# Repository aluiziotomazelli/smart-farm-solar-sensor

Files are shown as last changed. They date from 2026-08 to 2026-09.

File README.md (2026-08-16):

# Smart Farm Solar Sensor Node






A modular, low-power IoT peripheral node based on the **Seeed Studio XIAO ESP32-C3**, designed to measure real-time solar irradiance ($W/m^2$), estimate photovoltaic generation capacity for a 2.64 kWp solar array, monitor ambient/panel temperature and battery health, and broadcast telemetry via **ESP-NOW** to the central Smart Farm Hub.

---

## 1. Physical Principle & Measurement Model

- **Sensor Element:** Dedicated **5W** polycrystalline photovoltaic panel installed at the same tilt, azimuth, and environmental conditions as the main array.
- **Quantity Measured:** Short-circuit current ($I_{sc}$). $I_{sc}$ is strictly proportional to solar irradiance ($W/m^2$) and virtually immune to temperature drift ($\approx +0.04\% / ^\circ\text{C}$).
- **Precision Current Sensing:** High-side **INA226** power monitor with a **$0.1\Omega$ (SMD R100)** shunt resistor.
- **Thermal Monitoring & MPPT Compensation:** **DS18B20** 1-Wire temperature sensor attached to the panel to account for the negative temperature coefficient of photovoltaic cells ($\gamma_{Pmax} \approx -0.35\% / ^\circ\text{C}$).
- **Battery Health:** 1S Li-Po / 18650 voltage divider connected to ADC with calibration and threshold classification.

### Scale Matching & Empirical Benchmarks
- Nominal Panel $I_{sc}$ (at STC 1000 W/m²): $600\text{ mA}$
- Midday Empirical Peak: $720\text{ mA}$ ($1200\text{ W/m}^2$)
- Shunt Voltage at Peak: $V_{shunt} = 720\text{ mA} \times 0.1\Omega = 72\text{ mV}$ (88% of INA226 $\pm 81.92\text{ mV}$ full-scale range).

$$\text{Irradiance } (W/m^2) = \frac{I_{sc\_ma} \times 1000}{600} = \frac{I_{sc\_ma} \times 5}{3}$$

$$\text{Estimated STC Array Capacity } (W) = \frac{I_{sc\_ma} \times 2640\text{ W}}{600\text{ mA}} = I_{sc\_ma} \times 4.4$$

---

## 2. Hardware Pinout & Schematic (Seeed XIAO ESP32-C3)

### Pinout Table

| Pin | GPIO | Constant | Description |
| :----- | :--- | :--- | :--- |
| **D0** | `GPIO 2`  | `BATTERY_LEVEL_GPIO` | ADC battery divider input (240k / 240k, ADC1_CH2) |
| **D1** | `GPIO 3`  | `INA_ALERT_GPIO` | Conversion-ready alert & deep sleep dawn wake trigger  |
| **D2** | `GPIO 4`  | `STATUS_LED_GPIO` | Status LED visual indicator (diagnostic / state) |
| **D3** | `GPIO 5`  | `INA_VCC_GPIO` | Power gate control for INA226 power line |
| **D4** | `GPIO 6`  | `I2C_SDA_GPIO` | I2C Data line for INA226 |
| **D5** | `GPIO 7`  | `I2C_SCL_GPIO` | I2C Clock line for INA226 |
| **D6** | `GPIO 21` | *(Free)* | UART0 TX (Debug serial console) |
| **D7** | `GPIO 20` | *(Free)* | UART0 RX (Debug serial console) |
| **D8** | `GPIO 8`  | `DS18B20_GPIO` | 1-Wire data bus for DS18B20 digital temperature sensor |
| **D9** | `GPIO 9`  | `BOOT_BUTTON_GPIO` | Boot button / manual OTA mode trigger |
| **D10**| `GPIO 10` | *(Free)* | General purpose I/O |

### Circuit Schematic

Solar Sensor Schematic

---

## 3. Architecture & Task Concurrency

```
                        +---------------------------+
                        |     TelemetrySnapshot     | (Atomic thread-safe cache)
                        +---------------------------+
                               ^              ^
                updates battery|              |updates current & yield
                & temperature  |              |
                    +----------+--+        +--+---------------+
                    |SlowSensorsTask|       | InaSensorTask    |
                    | (Every 60s) |        | (Conversion sync)|
                    +------+------+        +--+---------------+
                           |                  |
                           v                  v
                 [DS18B20 + Battery]     [INA226 I2C]
                                              |
                                              v (ESP-NOW broadcast)
                                     +-----------------+
                                     | Smart Farm Hub  |
                                     +-----------------+
```

- **`InaSensorTask`**: High-frequency sampling task synchronized with INA226 conversion-ready interrupts. Updates exponential moving average (EMA) current and broadcasts `SolarSensorReport` via ESP-NOW.
- **`SlowSensorsTask`**: Low-frequency background task executing non-blocking battery ADC sampling (~16ms) and DS18B20 temperature conversions (~800ms) once per minute without stalling real-time control loops.
- **`DayNightController`**: Astronomical calculation engine determining solar noon, sunrise, sunset, and solar declination to dynamically orchestrate night deep-sleep modes.
- **`SolarSensorNvs`**: Dual-tier storage manager keeping runtime state in RTC Fast RAM across deep sleep cycles and committing to NVS Flash on dusk transitions.
- **`CommandHandler`**: Receives and executes remote commands via ESP-NOW (`SYNC_TIME`, `START_OTA`, `REBOOT`).

---

## 4. Telemetry Format (`SolarSensorReport`)

ESP-NOW payload is packed to **27 bytes** (`#pragma pack(push, 1)`):

```cpp
struct SolarSensorReport
{
    PowerProfile power_profile;   ///< Node energy mode (ALWAYS_ON, LOW_POWER, DEEP_SLEEP)
    uint16_t isc_current_ma;      ///< Instantaneous short-circuit current in mA (0 - 819 mA)
    uint16_t irradiance_wm2;      ///< Estimated solar irradiance in W/m² (0 - 1200 W/m²)
    int16_t  panel_temp_c;        ///< Sensor panel temperature in 0.1 °C (e.g. 255 = 25.5 °C)
    uint16_t battery_mv;          ///< Sensor node battery voltage in mV
    uint8_t  battery_percent;     ///< Sensor node battery percentage level (0-100%)
    BatteryState battery_state;   ///< Sensor node battery state (UNKNOWN, CRITICAL, LOW, NORMAL, FULL)
    SensorStatus status;          ///< Sensor health status (OK, ERROR_HARDWARE, etc.)
    uint16_t max_current_ma;      ///< Daily peak current recorded
    uint32_t daily_yield_mah;     ///< Accumulated daily current integral in mAh
    bool     is_night_mode;       ///< Night mode status flag
    uint64_t unix_time;           ///< UTC Epoch timestamp in milliseconds (0 if unsynced)
};
```

---

## 5. Building and Flashing Firmware

### Prerequisites
- ESP-IDF **v5.1+** (v5.5 recommended)

```bash
# Export ESP-IDF environment
source $HOME/paht_to_your_esp-idf/export.sh

# Build target firmware
idf.py set-target esp32c3
idf.py build

# Flash to connected device
idf.py -p /dev/ttyACM0 flash monitor
```

---

## 6. Running Host-Based Tests (Linux)

All components are fully decoupled through abstract interfaces and testable on Linux host using GoogleTest and GoogleMock without physical hardware.

### Running Individual Test Suites
```bash
cd host_test/test_slow_sensors_task
idf.py build
./build/test_slow_sensors_task.elf
```

### Running All Test Suites with CTest
```bash
cd host_test
mkdir -p build && cd build
cmake ..
ctest --output-on-failure
```

### Generating Unified Code Coverage
```bash
cd host_test/build
cmake --build . --target run_all_tests
# HTML report generated in host_test/coverage/index.html
```

---

## 7. License

This project is licensed under the MIT License - see the [LICENSE](LICENSE) file for details.

### Third-Party Acknowledgments

This project incorporates or links to the following third-party open-source libraries and drivers:

- **[espressif/onewire_bus](https://github.com/espressif/idf-extra-components/tree/master/onewire_bus)**: Copyright (c) Espressif Systems (Shanghai) CO LTD — Licensed under the [Apache License 2.0](https://www.apache.org/licenses/LICENSE-2.0).
- **[ESP-IDF](https://github.com/espressif/esp-idf)**: Copyright (c) Espressif Systems (Shanghai) CO LTD — Licensed under the [Apache License 2.0](https://www.apache.org/licenses/LICENSE-2.0).
- **[Embedded Template Library (ETL)](https://www.etlcpp.com/)**: Copyright (c) John Wellbelove — Licensed under the [MIT License](https://opensource.org/licenses/MIT).

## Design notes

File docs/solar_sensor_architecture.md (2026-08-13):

# Architecture and Testability Plan (Host-Test / TDD) - SolarSensor

## 1. Overview and Physical Model

The **SolarSensor** is a peripheral sensor node based on the **Seeed XIAO ESP32-C3** microcontroller, designed to monitor solar irradiance in real time and estimate the instantaneous power generation capacity of a **2.64 kWp (8 x 330W)** photovoltaic array operating with an inverter and no battery bank.

### 1.1 Measurement Principle
- **Sensor Element:** **5W** photovoltaic panel (polycrystalline), installed in the same location, tilt, orientation, temperature, and soiling conditions as the main array.
- **Measured Quantity:** Short-circuit current ($I_{sc}$). The $I_{sc}$ current is directly proportional to solar irradiance ($W/m^2$). Open-circuit voltage ($V_{oc}$) measurement was discarded because it varies little with irradiance.
- **Measurement Hardware:** **INA226** IC connected via **I2C** with a **$0.1\Omega$ (SMD R100)** shunt resistor.
- **Scale Matching:**
  - 5W Panel Specifications: $P_{max} = 5\text{W}$, $V_{oc} = 11.2\text{V}$, $V_{mp} = 9.25\text{V}$, $I_{sc\_nominal} = 0.6\text{A}$ (measured up to $0.7\text{A}$ under full sun).
  - Shunt voltage at $0.7\text{A}$: $V_{shunt} = 0.7\text{A} \times 0.1\Omega = 70\text{mV}$.
  - INA226 limit: $\pm 81.92\text{mV}$ (full scale of $819.2\text{mA}$ with $25\mu\text{A}/LSB$ resolution).
  - The measured peak of $0.7\text{A}$ operates at **~85% of full scale**, providing excellent resolution and 15% safety margin against overcurrent.

### 1.2 Physical Irradiance Model and Empirical Benchmarks

- **Datasheet Specifications (STC: 1000 W/m² @ 25°C)**:
  - Nominal Short-Circuit Current: $I_{sc\_nominal} = 600\text{ mA}$ ($0.6\text{ A}$).
  - Nominal Solar Irradiance: $1000\text{ W/m}^2$.

- **Empirical Field Measurement Benchmark**:
  - Measured at midday (clear sky, panel perpendicular to sun): $I_{sc\_measured} = 720\text{ mA}$.
  - Equivalent Solar Irradiance:
    $$\text{Irradiance} = \frac{720\text{ mA}}{600\text{ mA}} \times 1000\text{ W/m}^2 = 1200\text{ W/m}^2$$
  - INA226 Full Scale Verification ($R_{shunt} = 0.1\Omega$):
    $$V_{shunt} = 720\text{ mA} \times 0.1\Omega = 72\text{ mV}$$
    Operates at **88% of INA226 full-scale** ($\pm 81.92\text{ mV}$ / $819.2\text{ mA}$ max), providing a 100 mA (12%) safety margin.

- **Irradiance and STC Power Conversion Formulas**:
  1. **Irradiance Calculation ($W/m^2$)**:
     $$\text{irradiance\_wm2} = \frac{I_{sc\_ma} \times 1000}{600} = \frac{I_{sc\_ma} \times 5}{3}$$
  2. **Nominal Main Array STC Capacity ($W$)**:
     $$\text{estimated\_power\_w} = \frac{I_{sc\_ma} \times 2640\text{ W}}{600\text{ mA}} = I_{sc\_ma} \times 4.4$$

### 1.3 Temperature Effects and High-Precision MPPT Thermal Compensation

- **Why Short-Circuit Current ($I_{sc}$) Measures Pure Irradiance**:
  - The temperature coefficient of short-circuit current ($\alpha_{Isc}$) is negligible ($\approx +0.04\% / ^\circ\text{C}$).
  - Variations in cell temperature (10°C to 60°C) affect $I_{sc}$ by less than 1.5%. Therefore, $I_{sc}$ provides a temperature-immune measurement of pure solar irradiance ($W/m^2$).

- **Why a Panel Temperature Sensor Is Required for Maximum MPPT Precision**:
  - Photovoltaic cell open-circuit voltage ($V_{oc}$) and maximum power ($P_{max}$) have a strong **negative temperature coefficient** ($\gamma_{Pmax} \approx -0.35\% / ^\circ\text{C}$).
  - **Hot Conditions (55°C cell temp)**: The main array's MPPT output drops by $\sim 10.5\%$ ($2362\text{ W}$ instead of $2640\text{ W}$ nominal at 1000 W/m²).
  - **Cold Conditions (15°C cell temp)**: The main array's MPPT output increases by $\sim +3.5\%$ ($2732\text{ W}$ at 1000 W/m²).
  - **Future Hardware Addendum**: Adding a panel temperature sensor (e.g., DS18B20 / NTC attached to the back of the sensor panel) will allow applying the thermal correction factor:
    $$\text{Thermal\_Factor} = 1.0 + (T_{panel} - 25^\circ\text{C}) \times (-0.0035)$$
    $$P_{mppt\_compensated} = \text{estimated\_power\_w} \times \text{Thermal\_Factor}$$

---

## 2. Data Structures and Protocol

### 2.1 Local Persistence (`SolarStats` in `solar_sensor_stats.hpp`)
Maintained in **RTC RAM** (survives *deep sleep*) and synchronized periodically with **NVS**.

| Field | Type | Description |
| :--- | :--- | :--- |
| `magic` | `uint16_t` | Validation identifier (`0x534F` = "SO") |
| `version` | `uint8_t` | Persistence structure version |
| `gpio_wakeup_enabled`  | `bool` | External wakeup interrupt enable status |
| `is_night_mode` | `bool` | Flag indicating whether the node is operating in night mode |
| `last_battery_mv` | `uint16_t` | Last measured node battery voltage in mV |
| `last_battery_percent` | `uint8_t` | Last node battery percentage (0-100%) |
| `last_battery_state` | `BatteryState` | Battery classification (NORMAL, LOW, CRITICAL) |
| `max_current_ma` | `uint16_t` | Highest short-circuit current recorded during the day |
| `min_day_current_ma` | `uint16_t` | Lowest current recorded during the daytime period |
| `daily_yield_mah` | `uint32_t` | Accumulated daily current integral in mAh |
| `shunt_zero_offset_uv` | `int16_t` | INA226 zero offset measured during the night |
| `crc` | `uint32_t` | CRC32 for memory integrity validation |

### 2.2 ESP-NOW Telemetry (`SolarSensorReport` in `farm_protocol_types.hpp`)
Packed binary payload (`#pragma pack(push, 1)`), totaling **27 bytes** (ESP-NOW maximum: 230 bytes).

```cpp
struct SolarSensorReport
{
    PowerProfile power_profile;   ///< Node energy mode (ALWAYS_ON, LOW_POWER, DEEP_SLEEP)
    uint16_t isc_current_ma;      ///< Instantaneous short-circuit current in mA (0 - 819 mA)
    uint16_t irradiance_wm2;      ///< Estimated solar irradiance in W/m² (0 - 1200 W/m²)
    int16_t  panel_temp_c;        ///< Sensor panel temperature in 0.1 °C resolution (e.g. 255 = 25.5 °C, INT16_MIN if no sensor)
    uint16_t battery_mv;          ///< Sensor node battery voltage in mV
    uint8_t  battery_percent;     ///< Sensor node battery percentage level (0-100%)
    BatteryState battery_state;   ///< Sensor node battery classification
    SensorStatus status;          ///< Sensor health status (OK, ERROR_HARDWARE, etc.)
    uint16_t max_current_ma;      ///< Current peak recorded during the current day
    uint32_t daily_yield_mah;     ///< Accumulated daily current integral in mAh
    bool     is_night_mode;       ///< Indicates whether the node is in night mode
    uint64_t unix_time;           ///< UTC Epoch timestamp in ms (0 if not synchronized)
};
```

---

## 3. Software Architecture and Tasks
```
               +-------------------------------------------------------+
               |                   Hardware / INA226                   |
               +-------------------------------------------------------+
                                           | I2C Master (400kHz via IIna226Driver)
                                           v
               +-------------------------------------------------------+
               |                  ina_sensor_task                      |
               |  * Runs at 4-8 Hz                                     |
               |  * Reads INA226 registers via IIna226Driver           |
               |  * Exponential Moving Average (EMA) Digital Filter     |
               |  * Delta Detection (Delta I > 3% or 10mA)             |
               |  * Direct non-blocking ESP-NOW Telemetry Dispatch      |
               +-------------------------------------------------------+
                                 |                     |
             (Direct ESP-NOW TX) |                     | (Queue: InaSample)
                                 v                     v
+----------------------------------+   +----------------------------------+
|          EspNowManager           |   |            Main Task             |
| * Internal Queue & Worker Task   |   | * System State Machine & Storage |
| * Fire-and-Forget Radio TX       |   | * InaSample Consumer & Stats     |
| * Delta-triggered + 1s Heartbeat |   | * Read Error Counter & Watchdog  |
+----------------------------------+   | * Auto-Reboot on Hardware Error  |
                                       +----------------------------------+
```

1. **`InaSample` Data Contract (`ina_sensor_types.hpp`):**
   ```cpp
   struct InaSample {
       uint16_t  isc_current_ma;    ///< Instantaneous short-circuit current in mA
       uint16_t  bus_voltage_mv;    ///< Measured shunt/bus voltage
       bool      delta_detected;    ///< Flag indicating change exceeding delta threshold
       esp_err_t status;            ///< ESP_OK or I2C/INA226 hardware error status
       int64_t   timestamp_us;      ///< Microsecond timestamp of reading
   };
   ```

2. **`ina_sensor_task` (Frequency: 4 to 8 Hz):**
   - Performs periodic INA226 readings through `IIna226Driver`.
   - Applies Exponential Moving Average (EMA) digital filtering.
   - Detects abrupt irradiance changes ($\Delta I_{sc} > 3\%$ or $> 10\text{mA}$).
   - **Telemetry Dispatch:** On delta detection or 1s heartbeat, directly calls non-blocking `espnow_.send_data()` if reporting is enabled.
   - **Main Task Notification:** Enqueues `InaSample` (containing reading or `status` error) to `ina_sample_queue_`.

3. **`Main Task` (System Coordinator & Health Monitor):**
   - Consumes `InaSample` from `ina_sample_queue_`.
   - **Error Handling & Auto-Reboot:** 
     - Tracks consecutive I2C/hardware errors (`status != ESP_OK`).
     - **Watchdog Timeout:** Waits on `xQueueReceive` with a 2-second timeout. If `ina_sensor_task` freezes or fails 5 consecutive times, sets `stats_.status = SensorStatus::ERROR_HARDWARE` and triggers a clean system restart (`hal_system_.restart()`).
   - Manages state machine (`INIT`, `DAY_ACTIVE`, `DUSK_CHECK`, `NIGHT_SLEEP`, `OTA_MODE`).
   - Toggles `ina_sensor_task.set_reporting_enabled(false)` during `OTA_MODE` or `NIGHT_SLEEP`.

4. **INA226 Power & Hardware Control (High-Side GPIO Power Switching):**
   - **VCC Powering:** INA226 consumes only $\sim 0.33\text{mA}$ during measurement. Powered directly from a high-side ESP32-C3 GPIO pin (`OUTPUT HIGH`).
   - **Hardware Hard Reset:** Driving the VCC GPIO `LOW` for 50ms forces a complete Power-On Reset (POR) on the INA226, clearing stuck I2C bus lines without requiring a full MCU system reboot.
   - **Zero Parasitic Current:** During night `NIGHT_SLEEP`, VCC GPIO is set to `INPUT/LOW` and SDA/SCL lines are disabled, achieving absolute zero ($0.00\mu\text{A}$) parasitic draw.

5. **INA226 Dual-Mode ALERT Pin Strategy:**
   A single physical GPIO pin connected to the INA226 `ALERT` output operates in two distinct modes depending on system state:

   | Phase / State | INA226 ALERT Mode | ESP32-C3 Pin Configuration | Behavior / Function |
   | :--- | :--- | :--- | :--- |
   | **Day (`DAY_ACTIVE`)** | **Conversion Ready (`CVRF`)** | GPIO Interrupt (`gpio_isr_handler_add`) | INA226 triggers LOW on each completed hardware average. ISR issues `vTaskNotifyGiveFromISR`, waking `ina_sensor_task` with 0% idle CPU usage. |
   | **Night (`NIGHT_SLEEP`)** | **Shunt Over Limit (`SOL`)** | Deep Sleep Wakeup (`esp_deep_sleep_enable_gpio_wakeup`) | INA226 triggers LOW when $V_{shunt} > 0.3\text{mV}$ ($\sim 3\text{mA}$). Wakes the ESP32-C3 precisely at dawn. |

6. **ESP-NOW Radio Strategy:**
   - **Non-blocking** send (*fire-and-forget*) queued in the internal `EspNowManager` task (without waiting for a logical ACK, so the real-time flow is not blocked).
   - **Delta + Heartbeat Report:** Sends a packet when there is a significant current change or every 1 second (heartbeat).

---

## 4. Host Testability Strategy (`host_test`) & TDD

The repository adopts **Test-Driven Development (TDD)** in the native x86 test environment (`host_test`) using **GoogleTest** and **GoogleMock**. No logic or driver functionality should be added without a corresponding unit test.

### 4.1 Dependency Injection (DI) and Hardware Abstraction
All interaction with hardware, file systems, time, and the OS is performed through **pure C++ interfaces**:

- **I2C:** [`idf_hals::II2cHAL`](components/idf_hals/include/interfaces/i_hal_i2c.hpp) (Mock: [`MockI2cHAL`](components/idf_hals/mocks/mock_hal_i2c.hpp))
- **INA226 Driver:** `IIna226Driver` (Mock: `MockIna226Driver`)
- **Timing / RTOS:** [`ITimerHAL`](components/idf_hals/include/interfaces/i_hal_timer.hpp), [`IHalFreertos`](components/idf_hals/include/interfaces/i_hal_freertos.hpp)
- **Power / Sleep:** [`ISleepHAL`](components/idf_hals/include/interfaces/i_hal_sleep.hpp), `IBatteryMonitor`
- **Storage:** [`INvsCore`](main/include/interfaces/i_nvs_core.hpp)

### 4.2 Modules and Test Suites in `host_test`

| Test Suite | Test Target | What is tested / asserted |
| :--- | :--- | :--- |
| `Ina226DriverTest` | `Ina226Driver` | Register writes/reads through `MockI2cHAL`, correct $mV \to mA$ conversion calculation, ALERT register configuration, response to I2C failures (NACK/timeout). |
| `SolarMathTest` | Solar calculation functions | Conversion from $I_{sc} \to \text{Irradiance } (W/m^2)$, 2.64 kWp array power estimation, daily integral in mAh, Exponential Moving Average (EMA) filter. |
| `SolarSensorTaskTest` | Sampling Task | Sampling rate, report triggering by $\Delta I$ variation, instantaneous noise handling, shared state update. |
| `SolarSensorAppTest`  | `SolarSensor` App Class | State machine transitions (Day $\leftrightarrow$ Night), statistics saving to NVS/RTC, OTA trigger dispatch. |

### 4.3 TDD Development Cycle (Red-Green-Refactor)

1. **Step 1 (Red - Write the Test):**
   Create the test file or add a `TEST_F` to the appropriate suite in `host_test/test_solar_sensor/main/`. Define mock expectations (`EXPECT_CALL(...)`) and call the method of the class under test.
2. **Step 2 (Green - Implement the Minimum):**
   Write only the code strictly required in the component/main so the test passes. Run `idf.py host_test` or the host CMake build.
3. **Step 3 (Refactor - Improve Safely):**
   Clean up and optimize the implementation with the assurance that the test suite guarantees no regression has been introduced.

---

## 5. Next Implementation Steps

1. Create the `IIna226Driver` interface and its `MockIna226Driver` mock.
2. Develop the `host_test` tests for `Ina226Driver` based on `MockI2cHAL`.
3. Implement the `Ina226Driver` class until all unit tests pass.
4. Implement the tests for the solar math functions (`SolarMathTest`).
5. Integrate sampling and `SolarSensorReport` generation into `SolarSensor`.

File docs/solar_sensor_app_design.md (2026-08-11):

# Solar Sensor — Design da Aplicação (Revisão de Arquitetura)

> Documento de design resultante da revisão de arquitetura do app `SolarSensor`.
> Complementa [`solar_sensor_architecture.md`](solar_sensor_architecture.md) (visão física/protocolo)
> e [`session-ses_011f.md`](session-ses_011f.md) (visão do `run()` atual).

---

## 1. Requisitos da aplicação

1. **Ler dados do sensor** — `InaSensorTask` (INA226, 4-8 Hz, EMA, delta).
2. **Enviar telemetria via ESP-NOW** quando necessário (delta ou heartbeat 1s). O pacote é primordial para o hub tomar decisões.
3. **Decidir entrada em deep sleep** (dusk/dawn) — com base em corrente + relógio.
4. **Receber comandos do hub** — `start_ota`, `reboot` forçado, `sync_time`.
5. **Processo de OTA completo** — parar o que for supérfluo (inclusive competição de rádio), conectar à internet, processar o OTA, desconectar, reiniciar; no boot seguinte verificar `pending verify`, aguardar o `init()` saudável, aceitar o firmware novo ou dar rollback.
6. **Verificar bateria** e enviar junto com os dados de leitura (não primordial — bateria é só backup). A `InaSensorTask` **não deve** ter acesso aos dados de bateria.

---

## 2. Estado atual (as-is) — fatos verificados no código

| Item | Situação |
|---|---|
| `SolarSensor::run()` | Stub (`solar_sensor.cpp:143-147`): loga e retorna. `main.cpp:162` chama uma vez. |
| `process_ina_samples()`, `enter_deep_sleep()`, `save_persistent_state()`, `recover_ina_hardware()`, `check_firmware()`, `send_ota_report()`, `connect_wifi_with_retry()` | Implementados e testados, **nunca chamados** (o `run()` não os orquestra). |
| Telemetria | A `InaSensorTask` envia, mas o `SolarSensorReport` sai incompleto: bateria/stats/`is_night_mode` = 0; `unix_time` = ms desde o boot (monotônico), **não** epoch. |
| `rx_queue_` (app_rx_queue) | Nunca é consumida — comandos do hub são **descartados**. |
| Triggers de OTA | `btn_trigger_.arm()` e `espnow_trigger_.arm()` **nunca são chamados**; `EspNowOtaTrigger::notify()` não é invocado por ninguém. OTA via trigger está 100% desligado. |
| `send_data(require_ack=false)` | Non-blocking: enfileira na TX queue interna do `EspNowManager` (task própria, prio 9). Bloqueia no máximo 100ms se a fila (30) estiver cheia; retorna `ESP_FAIL` e o produtor reenvia no ciclo seguinte. |
| `CoreStorage` | Já possui `has_valid_time`, `last_sync_unix_time_ms`, `power_profile`, `sleep_interval_s`, `last_wake` (`WakeSource`). |
| `TimeSyncCommand` (farm) | Layout idêntico ao `time_manager::TimeSyncPacket` (12 bytes packed) → cast direto no handler. |
| Protocolo de comandos | Dois níveis: **transporte** `espnow::CommandType` (`protocol_types.hpp`): `START_OTA` (0x01), `REBOOT` (0x02), `SET_REPORT_INTERVAL` (0x03). **Aplicação** `farm::CommandType` (`farm_protocol_types.hpp`): `SLEEP_OVERRIDE` (0x40), `PUMP_*` (0x41/0x42), `SYNC_TIME` (0x43). |
| Bateria | `main.cpp` cria `bat_monitor` mas **não injeta** no `SolarSensor`. |

---

## 3. Decisões de arquitetura (com justificativa)

### D1 — Quem envia a telemetria: a própria `InaSensorTask`

**Decisão:** a task continua sendo a produtora do envio.

**Justificativa:**
- O dado está mais fresco na task (sample acabou de ser lido) e não depende do agendamento do main.
- A preocupação "main ocupado com gravação flash atrasa o pacote" **já é resolvida pelo `EspNowManager`**: ele possui fila TX interna + task própria (prio 9). O produtor apenas enfileira — non-blocking.
- **O `EspNowManager` já é o dispatcher.** Uma classe/task intermediária de dispatch seria uma fila redundante na frente de outra fila (telemetria → queue dispatcher → queue EspNowManager → rádio).
- Só valeria um dispatcher se houvesse necessidade real de **prioridade** (ACK de OTA na frente da telemetria) ou **coalescência** (descartar heartbeat velho). Hoje: YAGNI. Revisitar se virar problema observado.

**Ressalva:** `send_data` pode bloquear até 100ms com a TX queue cheia — aceitável para telemetria; o código já trata falha de envio (não atualiza `last_reported_*` e reenvia no ciclo seguinte).

### D2 — Report completo: `TelemetrySnapshot` compartilhado (mutex)

**Decisão:** um struct de ~25 bytes protegido por mutex, escrito pelo main e lido pela task na hora do envio.

**Justificativa:** a task não pode (e não deve) ter acesso a bateria/stats — esses dados vivem no `SolarSensor`/`BatteryMonitor`. O snapshot transfere só os *valores*, sem acoplar a task a esses componentes. (Tempo é exceção: a task lê o `ITimeManager` diretamente para o `unix_time` — ver D4.)

### D3 — `power_profile`: não entra no snapshot

**Decisão:**
- A task **hardcoda `ALWAYS_ON`** — semanticamente correto, pois ela só envia quando `reporting_enabled_ && sampling_enabled_` (modo dia).
- O report final `DEEP_SLEEP` é **evento do main**: antes de `enter_deep_sleep()`, o main seta `core_.power_profile = DEEP_SLEEP`, monta o `SolarSensorReport` (profile `DEEP_SLEEP`, `is_night_mode=true`, bateria do snapshot) e envia com `require_ack=true` (pode bloquear — é a última coisa antes de dormir).

### D4 — `unix_time` do report: task calcula via `ITimeManager` no envio

**Decisão:** o `unix_time` do report é calculado pela task **no momento do envio**, lendo o relógio de sistema:

```cpp
// InaSensorTask::send_telemetry_report()
report.unix_time = time_.is_synchronized() ? time_.get_timestamp_ms() : 0;
```

A task ganha `time_manager::ITimeManager&` no construtor. O `TelemetrySnapshot` **não carrega nenhum campo de tempo** (nem `unix_time_ms`, nem ponto de sync).

**Justificativa:**
- `ITimeManager::get_timestamp_ms()` lê o relógio de sistema (`gettimeofday`), que no C3 é baseado no RTC e **continua contando durante o deep sleep** — a task obtém o epoch real no instante do envio, sem "ponto de sync" no snapshot nem aritmética monotônica. A premissa do D4 antigo (`esp_timer` sobreviver ao deep sleep) deixa de existir.
- O valor nunca fica defasado: é lido na hora, junto com o sample.
- O snapshot fica mais simples (só bateria/stats/`is_night_mode`).
- Fluxo coerente com o `CommandHandler`: `SYNC_TIME` → `time_manager.sync_from_time_packet()` acerta o relógio de sistema → o próximo report da task já reflete o epoch novo.

**Guard `is_synchronized()`:** sem sync o relógio de sistema está na base (epoch ~0), o que também dispararia o auto-sync do hub por diff enorme. Com o guard, o valor vai `0` = "não sincronizado" (mesma semântica do water-tank com `has_valid_time == false`).

**Responsabilidade do hub (fora deste repo — pode ser feito, o hub ainda não tem `solar_sensor_handler`):** **tolerar `unix_time == 0`** — não disparar auto-sync quando o valor for 0; a detecção de discrepância (diff > 5s) só deve valer para `unix_time > 0`. Sem isso, o `0` causaria tempestade de `sync_time` a cada report.

**Manter o campo no `SolarSensorReport`:** sim — remover seria mudança de protocolo (struct packed, afeta o hub) para economizar 8 bytes num pacote de 27. `0` já significa "não sincronizado".

### D5 — OTA não exige deinit do espnow

**Decisão:** durante o download, `espnow.set_channel_policy(ChannelPolicy::FIXED)` (AP domina o canal); ao falhar, volta `SCAN`. **A amostragem continua** (o watchdog do `process_ina_samples()` permanece vivo) — só o reporting é desligado.

**Justificativa:** a API `set_channel_policy` já existe exatamente para isso; evita o ciclo pesado de `deinit()`/`init()` do EspNowManager.

### D6 — Heartbeat interno do espnow: mantém 0

**Decisão:** a telemetria de 1s **é** o sinal de liveness. O node não precisa (nem deve) saber se está "offline" — isso é responsabilidade de quem monitora (hub). O node mantém `heartbeat_interval_ms = 0`.

**Esclarecimento (estado atual):** `get_offline_peers()` é método **público do `espnow_manager`** (não do hub app) e **ainda não é usado em lugar nenhum**. O hub não tem método próprio de detecção de offline. O `espnow_manager` já faz a detecção internamente, mas a API é pobre: retorna um `etl::vector` com **todos** os nodes offline — o hub precisaria iterar o vetor para saber se um node específico caiu.

**Pendência:** estudo futuro da API do `espnow_manager` (ver §9). Não muda nada no solar sensor por ora.

### D7 — `SLEEP_OVERRIDE`: não se aplica

**Decisão:** comando ignorado (ACK `ERROR_INVALID_DATA`) — é para nodes como o water-tank. O solar sensor não usa `sleep_interval_s` override.

---

## 4. Estrutura proposta (target)

```
                    ┌─────────────────────────────────────────────┐
                    │           SolarSensor (coordenador)         │
                    │  run(): loop ~7Hz (block no sample queue)   │
                    │   ├─ TelemetrySnapshot (escreve)            │
                    │   ├─ CommandHandler.process()               │
                    │   ├─ OtaCoordinator.tick()                  │
                    │   ├─ DayNightController.update()            │
                    │   ├─ battery read (periódico)               │
                    │   └─ save_persistent_state (15min)          │
                    └──────────────┬──────────────────────────────┘
                       samples q   │                │ battery/time/sync
                                  ▼                ▼
                    ┌────────────────────────┐  ┌──────────────────────┐
                    │ InaSensorTask (task)   │  │ BatteryMonitor       │
                    │  - sample + telemetria │  │ TimeManager (sync)   │
                    │  - lê snapshot (mutex) │  └──────────────────────┘
                    └───────────┬────────────┘
                                │ send_data (non-blocking)
                                ▼
                    ┌─────────────────────────────┐
                    │ EspNowManager (JÁ é o       │
                    │ dispatcher: fila + tasks)   │
                    └─────────────────────────────┘
```

**Princípios:**
- **Nenhuma task nova.** O TX já tem task própria no EspNowManager.
- **Nenhuma classe de dispatch nova.** Estado compartilhado para o que é estado; send direto para o que é evento.
- `SolarSensor` vira coordenador fino: o `run()` é um script que faz tick em subsistemas coesos.

---

## 5. Detalhamento por classe

### 5.1 `TelemetrySnapshot` (nova — peça-chave)

```cpp
struct TelemetrySnapshotData {   // ~25 bytes, protegido por mutex
    uint16_t    battery_mv;
    uint8_t     battery_percent;
    farm::BatteryState battery_state;
    uint16_t    max_current_ma;
    uint32_t    daily_yield_mah;
    bool        is_night_mode;
};
```

- **Quem escreve:** main (bateria a cada N segundos, stats após processar samples, `is_night_mode` nas transições).
- **Quem lê:** `InaSensorTask::send_telemetry_report()` (lock → copy → unlock → preenche report; `unix_time` vem do `ITimeManager` — ver D4).
- **Sincronização:** C3 é single-core → mutex simples ou critical section resolve.
- **Injeção:** referência no construtor da task (e no `SolarSensor`). O construtor da task também ganha `time_manager::ITimeManager&` (D4) → atualizar host tests (inclui criar `MockTimeManager`).
- **`power_profile` fica FORA** (ver D3).

### 5.2 `CommandHandler` (nova, pequena, poling do `run()`)

```cpp
CommandHandler(QueueHandle_t rx_queue, IEspNowManager& espnow, ITimeManager& time,
               IOtaTrigger& espnow_ota_trigger, ISystemHAL& hal_system, CoreStorage& core);

void process();   // drena rx_queue_ (chamado no loop ~7Hz)
```

O comando chega no `AppMessage` com `msg_type = COMMAND` e o valor do `CommandType` **no campo `msg.payload_type`** (o transporte encoda o comando nesse campo do header).

| `msg.payload_type` | Ação |
|---|---|
| `espnow::CommandType::START_OTA` (0x01) | `espnow_ota_trigger.notify()` → `OtaCoordinator`. |
| `espnow::CommandType::REBOOT` (0x02) | `hal_system.restart()`. |
| `espnow::CommandType::SET_REPORT_INTERVAL` (0x03) | Fora dos requisitos atuais — ACK `ERROR_INVALID_DATA` (candidato futuro: ajustar o `heartbeat_interval_ms` da task). |
| `farm::CommandType::SYNC_TIME` (0x43) | `time_.sync_from_time_packet(*reinterpret_cast<const TimeSyncPacket*>(msg.payload))`; atualiza `core_.has_valid_time` / `core_.last_sync_unix_time_ms`. |
| `farm::CommandType::SLEEP_OVERRIDE` / `PUMP_*` (0x40-0x42) | Ignora (ACK `ERROR_INVALID_DATA`). |
| qualquer | Se `msg.requires_ack` → `espnow.confirm_reception(msg.sender_id, msg.sequence_number, ok/err)`. |

### 5.3 `OtaCoordinator` (extração — a maior, implementar por último)

Máquina de estados (transpõe reboot):

```
IDLE →(trigger: botão/espnow)→ PREPARING:
         - ina_task.set_reporting_enabled(false)
         - espnow.set_channel_policy(FIXED)
         - wifi connect (retry)
      → DOWNLOADING:
         - ota_manager.start_ota()
         - poll get_status() até DONE/FAILED   [samples continuam → watchdog vivo]
      → SUCCESS → hal_system.restart() → VERIFYING (próximo boot)
      → FAILED  → espnow.set_channel_policy(SCAN); reporting on → IDLE

VERIFYING (boot):
  pending_firmware_verify_ && session_healthy → confirm_app_valid()
      + report OTA_STATUS_REPORT(CONFIRMED_SUCCESS) + commit versão → IDLE
  senão → report OTA_STATUS_REPORT(ROLLBACK_TRIGGERED, HEALTH_CHECK_FAILED)
      + rollback_and_reboot()
```

**Deps:** `ota_manager`, `wifi`, `espnow` (channel policy + `send_data` para o report), `ina_task` (só `set_reporting_enabled`), `hal_system`, `core_`.

**Alternativa de desacoplamento:** interface `IOtaApp` (implementada pelo `SolarSensor`) para os side-effects (`set_telemetry_enabled`, channel policy, reboot). Como os componentes já têm interfaces com mocks no repo, injetar direto é menos abstração nova — decidir na implementação.

### 5.4 `DayNightController` (nova, lógica pura — melhor custo/benefício)

Sem I/O, só decisões → testável sem mock.

- `update(current_ma)`: se dia e `current < threshold` → request sleep.
  - **Com clock válido:** confirma também que a hora está dentro da janela de confiança (**dusk = corrente + relógio**).
  - **Sem clock válido:** usa só corrente — ver D8 abaixo.
- `classify_wake(cause, now)`:
  - `GPIO` (ALERT low) → dia (amanhecer).
  - `TIMER` na hora de calibração → **modo calibração**: ler shunt zero offset (madrugada, sem luz), persistir, voltar a dormir.
  - `TIMER` fora da janela → voltar a dormir.
- **Config:** `dusk_current_threshold_ma` (ver D8), `dusk_hour_window`, `calibration_wake_hour` — `dusk_hour_window` e `calibration_wake_hour` a medir com sensor real (pendente).

### 5.5 `StatsManager` — **adiado**

Stats + NVS permanecem no `SolarSensor`. Extrair apenas quando a integral diária (`daily_yield_mah`) e a calibração de offset ganharem lógica real. O snapshot já desacopla stats da task.

### 5.6 `SolarSensor` (após refactor)

- Construtor perde ~6-7 deps (absorvidas pelos subsistemas).
- `run()` vira orquestração de ticks.
- Mantém: watchdog/recuperação INA, transições de sleep, storage (por ora), composição.

---

## 6. Gaps / pendências de protocolo e código

1. **`START_OTA`/`REBOOT`/`SET_REPORT_INTERVAL` já existem** em `espnow::CommandType` (`protocol_types.hpp`) — não há gap de protocolo para esses. O gap real é de **wiring**: `rx_queue_` não é consumida (comandos nunca despachados) e os triggers não são armados.
2. **Triggers nunca são armados** (`btn_trigger_.arm()`, `espnow_trigger_.arm()`) e `EspNowOtaTrigger::notify()` não é chamado por ninguém → wire do gatilho de OTA é 100% novo.
3. **`unix_time` do report é monotônico**, não epoch — placeholder até a task ler o `ITimeManager` no envio (D4) e o hub tolerar `unix_time == 0`.
4. **`rx_queue_` nunca consumida** → comandos descartados (requisito 4 inteiro em falta).
5. **Bateria não injetada** no `SolarSensor` → campos de bateria sempre 0.
6. **API de offline do `espnow_manager`** — `get_offline_peers()` é público mas não usado; hub não tem detecção própria. Ver §9 (estudo futuro; nada a mudar no node por ora).
7. **Dusk sem clock válido** — comportamento a definir (ver §7).

---

## 7. Decisões em aberto / fechadas

1. **Indireção do `START_OTA`:** manter o `EspNowOtaTrigger` (CommandHandler chama `notify()` → listener) ou o `CommandHandler` chamar o `OtaCoordinator` direto? (Mantive o trigger por reutilizar a abstração `IOtaTrigger` já existente.) — **EM ABERTO**
2. **Dusk sem clock válido** → **FECHADO (D8 abaixo)**.
3. **Granularidade da implementação:** incremental — **FECHADO (§8 abaixo)**.

### D8 — Dusk sem clock válido: corrente abaixo de `DEFAULT_DUSK_CURRENT_MA`

**Decisão:** quando `ITimeManager::is_synchronized() == false`, o `DayNightController`
decide entrar em sleep baseando-se **apenas na corrente**. Threshold inicial:

```cpp
// ina_sensor_types.hpp
/// Corrente abaixo da qual o node considera que é entardecer (dusk).
/// Valor inicial conservador; calibrar com sensor real no campo.
static constexpr uint16_t DEFAULT_DUSK_CURRENT_MA = 1; // < 1 mA → entra em sleep
```

**Justificativa:**
- O node deve ser capaz de entrar em deep sleep mesmo sem nunca ter recebido
  `SYNC_TIME` do hub (ex.: primeiro deploy, hub offline).
- 1 mA é abaixo do ruído de dark current do painel — qualquer irradiância
  real gera corrente muito maior. Conservador o suficiente para não dormir
  durante o dia por falso negativo.
- A constante vive em `ina_sensor_types.hpp`, junto a `DEFAULT_DAWN_WAKEUP_ALERT_LIMIT`
  (mesma convenção: limites de corrente relacionados ao ciclo dia/noite do INA).
- Calibrar o valor real (e a janela de hora) com multímetro/sensor no campo;
  atualizar a constante e o comentário de cálculo no mesmo estilo de
  `DEFAULT_DAWN_WAKEUP_ALERT_LIMIT`.

**Com clock válido:** a janela de hora é AND com a corrente — evita dormir
num pico de nuvem passageira no meio do dia.

---

## 8. Sequência de implementação (incremental, TDD)

> Regra do repo: nenhuma lógica sem teste correspondente (host_test, GoogleTest/GoogleMock).

1. **`TelemetrySnapshot` + `ITimeManager` na task (1a)** — testes: main escreve / task lê; report completo; `unix_time` real via `ITimeManager` (sincronizado) / `0` (não sincronizado). Muda construtor da task — `TelemetrySnapshot&` + `ITimeManager&` → ajustar `SolarSensorTaskTest` e criar `MockTimeManager`.

2. **`BatteryMonitor` injetado no `SolarSensor` (1b)** — adiciona `IBatteryMonitor&` ao construtor de `SolarSensor` e ao wiring em `main.cpp`. Leitura periódica de bateria no `run()` → escreve no snapshot. Testes: snapshot com bateria real; campos não-zero no report.
   > ⚠️ **Atenção:** Os passos 1a e 1b podem ser commitados em qualquer ordem, mas o report só fica completo com os dois aplicados. Enquanto 1b não estiver feito, os campos de bateria do snapshot são inicializados dos valores persistidos no `SolarStats` (carregados no boot via NVS/RTC), o que é aceitável como fallback.

3. **`CommandHandler`** — testes: dispatch `SYNC_TIME`, ignore `SLEEP_OVERRIDE`, ack `confirm_reception`. (Desbloqueia requisito 4.)

4. **`DayNightController`** — testes: dusk só por corrente (`DEFAULT_DUSK_CURRENT_MA`), dusk por corrente+hora (clock válido), `classify_wake` GPIO/TIMER/calibração. (Lógica pura, sem mock.)

5. **`run()` integrando 1-4** — testes de app: drena fila, watchdog restart, dusk → sleep, wake GPIO → dia.
   > **Atenção:** `ota_triggered_` (flag atômica em `SolarSensor`) é setada em `on_ota_triggered()` mas nunca lida. Antes do `OtaCoordinator` existir, o `run()` deve checar essa flag e chamar `espnow_trigger_.notify()` / iniciar o fluxo de OTA inline.

6. **`OtaCoordinator`** — por último (maior; a versão atual dentro do `SolarSensor` já funciona): trigger armado, channel policy, download, verify no boot, rollback.

---

## 9. Estudos futuros (fora do escopo do SolarSensor)

### 9.1 API de detecção de offline no `espnow_manager`

- **Problema:** o `espnow_manager` já detecta offline internamente (e bem), mas a API só expõe `get_offline_peers()` — um `etl::vector` com **todos** os peers offline. O hub precisa iterar o vetor para saber se um node específico está offline.
- **Proposta:** métodos dedicados na API, ex.: `bool is_node_offline(NodeId)` / `is_node_online(NodeId)`, sem expor o vetor.
- **Pergunta em aberto:** a detecção de offline considera **qualquer pacote recebido** (inclusive os internos de comunicação automática — scan, pairing, ack) ou depende do `heartbeat_interval_ms` configurado por peer? Evidência no código: `NOTIFY_LINK_ALIVE` é setado em qualquer recepção válida de pacote (`protocol_types.hpp`). Isso determina se a telemetria de 1s do solar sensor mantém o peer "vivo" no hub.
- **Impacto no solar sensor:** nenhum por ora — o node continua com `heartbeat_interval_ms = 0` (telemetria é o liveness). O estudo é do lado espnow_manager/hub.

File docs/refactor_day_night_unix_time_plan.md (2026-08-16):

# Refactoring Plan: `DayNightController` — Unix Time API + Dawn Alert in mA

## Goal

Two related cleanups to eliminate boilerplate and improve safety:

1. **Replace `(bool is_synced, uint8_t hour, uint8_t minute, uint16_t day_of_year)` params** with `std::optional<time_t> unix_time` across all three `DayNightController` methods. The decomposition of `tm_hour`, `tm_min`, `tm_yday` moves inside the controller, where it belongs (domain logic). The three `localtime_r()` boilerplate blocks scattered in `solar_sensor.cpp` are eliminated.

2. **Replace raw INA226 alert register `DEFAULT_DAWN_WAKEUP_ALERT_LIMIT = 12`** with a human-readable `dawn_alert_current_ma` field in `InaSensorConfig`. The conversion to the raw 16-bit register value is computed once inside `InaSensorTask::prepare_for_sleep()`, using the shunt resistance stored in `Ina226Config`.

---

## User Review Required

> [!IMPORTANT]
> `classify_wake()` currently classifies **any** GPIO wakeup as `DAWN_GPIO`, ignoring time of day. This refactoring is the right moment to also fix that bug (the field sleep/wake loop you observed at dusk). The fix is included in the plan as **Step 2c**. If you want to separate the two concerns into independent commits, let me know.

> [!IMPORTANT]
> `localtime_r()` converts the UTC `time_t` to **local time using the system TZ**. In ESP-IDF, the TZ is configured via `setenv("TZ", ...)`. The controller already has `tz_offset_hours` in `DayNightConfig`, but currently that field is only used conceptually (not in the computation). The tests on the host will call `localtime_r()` with the system TZ, which may differ from the target TZ. This is acceptable since the tests already pass fixed `hour`/`minute` values — but after the refactoring, the host tests need to supply a `time_t` that matches UTC so `localtime_r()` returns the expected values, or we can use `gmtime_r()` + `tz_offset_hours` internally (pure, no system TZ dependency). **Which do you prefer?**
> - Option A: Use `localtime_r()` — simple, relies on system TZ (consistent with how the ESP32 sets TZ via SNTP today).
> - Option B: Use `gmtime_r()` + `config_.tz_offset_hours` — pure, no system-level TZ dependency, easier to test portably.

---

## Open Questions

> [!IMPORTANT]
> **Dawn alert threshold**: Currently `DEFAULT_DAWN_WAKEUP_ALERT_LIMIT = 12` raw units ≈ `0.3 mA`. This is clearly too sensitive (triggered by dusk noise). What should the new `dawn_alert_current_ma` default value be? Suggestion: **`5 mA`** (same as `DEFAULT_DAWN_CURRENT_THRESHOLD_MA`), so that the INA only wakes the MCU when the panel is already producing meaningful current.

---

## Background

### The 3 Boilerplate Blocks in `solar_sensor.cpp`

All three call sites repeat the exact same pattern:

```cpp
// Block 1 — run_day_cycle (L237-248)
bool is_synced = time_manager_.is_synchronized();
uint8_t hour = 0; uint8_t minute = 0; uint16_t day_of_year = 81;
if (is_synced) {
    time_t now = time_manager_.get_timestamp_sec();
    struct tm timeinfo{};
    localtime_r(&now, &timeinfo);
    hour = static_cast<uint8_t>(timeinfo.tm_hour);
    minute = static_cast<uint8_t>(timeinfo.tm_min);
    day_of_year = static_cast<uint16_t>(timeinfo.tm_yday + 1);
}
process_ina_samples(is_synced, hour, minute, day_of_year); // -> should_enter_night_mode

// Block 2 — enter_deep_sleep (L717-728)
// Same 10 lines again -> calculate_night_sleep_time_us

// Block 3 — evaluate_boot_mode (L840-847)
// Partial repeat (only hour) -> classify_wake
```

### Current Signatures (to be replaced)

```cpp
// day_night_controller.hpp
bool should_enter_night_mode(
    uint16_t current_ma,
    bool is_time_synced,
    uint8_t current_hour_local,
    uint8_t current_minute_local,
    uint16_t day_of_year);

WakeType classify_wake(
    bool is_gpio_wakeup,
    uint16_t current_ma,
    bool is_time_synced,
    uint8_t current_hour_local) const;

uint64_t calculate_night_sleep_time_us(
    bool is_time_synced,
    uint8_t current_hour_local,
    uint8_t current_minute_local,
    uint16_t day_of_year) const;
```

---

## Proposed Changes

### Step 1 — INA226 Alert Limit in mA

---

#### [MODIFY] `ina_sensor_types.hpp`

Replace the raw constant with a human-readable default in mA, and update the comment:

```diff
-/**
- * @brief Default Shunt Over Voltage raw threshold for dawn wakeup detection.
- * Calculation: I_dawn = ~0.3 mA, V_sh = 30 uV, raw = 30/2.5 = 12
- */
-static constexpr uint16_t DEFAULT_DAWN_WAKEUP_ALERT_LIMIT = 12;
+/**
+ * @brief Default dawn wakeup current threshold in mA.
+ *
+ * The INA226 SHUNT_OVER_VOLTAGE alert fires when the shunt current
+ * exceeds this value, waking the MCU from deep sleep at dawn.
+ * Must be high enough to reject dusk noise (recommend >= 5 mA).
+ */
+static constexpr uint16_t DEFAULT_DAWN_ALERT_CURRENT_MA = 5;
```

Add a new field to `InaSensorConfig`:

```diff
 struct InaSensorConfig
 {
     uint16_t delta_threshold_ma = 10;
     float delta_threshold_percent = 0.03f;
     uint16_t heartbeat_interval_ms = 1000;
     bool enable_ema_filter = true;
     float ema_alpha = 0.8f;
     uint32_t task_stack_size = 4096;
     UBaseType_t task_priority = 5;
+    uint16_t dawn_alert_current_ma = DEFAULT_DAWN_ALERT_CURRENT_MA; ///< INA dawn wakeup current threshold in mA
     InaNightConfig night_config{};
 };
```

#### [MODIFY] `ina_sensor_task.cpp` — `prepare_for_sleep()`

Replace static constant with dynamic conversion:

```diff
+// INA226 Shunt Voltage LSB = 2.5 uV/LSB.
+// V_shunt_uv = I_ma * R_shunt_mohm  =>  raw = V_shunt_uv / 2.5
+// With R_shunt = 100 mOhm: raw = I_ma * 100 / 2.5 = I_ma * 40
+float r_shunt_mohm = ina_day_config_.r_shunt_ohms * 1000.0f;
+float v_shunt_uv = static_cast<float>(config_.dawn_alert_current_ma) * r_shunt_mohm;
+uint16_t alert_limit = static_cast<uint16_t>(v_shunt_uv / 2.5f);
 err = driver_.configure_alert(
-    static_cast<uint16_t>(ina226::AlertFlag::SHUNT_OVER_VOLTAGE), DEFAULT_DAWN_WAKEUP_ALERT_LIMIT);
+    static_cast<uint16_t>(ina226::AlertFlag::SHUNT_OVER_VOLTAGE), alert_limit);
```

> [!NOTE]
> `InaSensorTask` already receives the `Ina226Config` (which contains `r_shunt_ohms`) through its constructor. The conversion happens once at `prepare_for_sleep()` time — no new dependencies needed.

---

### Step 2 — `DayNightController` Unix Time API

---

#### [MODIFY] `day_night_controller.hpp`

Replace decomposed time params with `std::optional<time_t>`:

```diff
+#include <ctime>
+#include <optional>

 bool should_enter_night_mode(
     uint16_t current_ma,
-    bool is_time_synced,
-    uint8_t current_hour_local,
-    uint8_t current_minute_local,
-    uint16_t day_of_year);
+    std::optional<time_t> unix_time);

 WakeType classify_wake(
     bool is_gpio_wakeup,
     uint16_t current_ma,
-    bool is_time_synced,
-    uint8_t current_hour_local) const;
+    std::optional<time_t> unix_time) const;

 uint64_t calculate_night_sleep_time_us(
-    bool is_time_synced,
-    uint8_t current_hour_local,
-    uint8_t current_minute_local,
-    uint16_t day_of_year) const;
+    std::optional<time_t> unix_time) const;
```

Add a private helper that centralizes the `localtime_r` decomposition:

```cpp
private:
    struct LocalTime {
        uint8_t hour;
        uint8_t minute;
        uint16_t day_of_year;
    };
    LocalTime decompose(time_t unix_time) const;
```

#### [MODIFY] `day_night_controller.cpp`

Add `decompose()` implementation:

```cpp
DayNightController::LocalTime DayNightController::decompose(time_t unix_time) const
{
    struct tm t{};
    localtime_r(&unix_time, &t);
    return {
        static_cast<uint8_t>(t.tm_hour),
        static_cast<uint8_t>(t.tm_min),
        static_cast<uint16_t>(t.tm_yday + 1)
    };
}
```

Update `should_enter_night_mode()`:

```diff
-bool DayNightController::should_enter_night_mode(
-    uint16_t current_ma, bool is_time_synced,
-    uint8_t current_hour_local, uint8_t current_minute_local, uint16_t day_of_year)
+bool DayNightController::should_enter_night_mode(
+    uint16_t current_ma, std::optional<time_t> unix_time)
 {
-    if (is_time_synced) {
+    if (unix_time.has_value()) {
-        SolarDayInfo day_info = calculate_solar_day(day_of_year);
-        float current_time_float = static_cast<float>(current_hour_local) + ...
+        auto [hour, minute, day_of_year] = decompose(*unix_time);
+        SolarDayInfo day_info = calculate_solar_day(day_of_year);
+        float current_time_float = static_cast<float>(hour) + (static_cast<float>(minute) / 60.0f);
         ...
     } else {
         required_samples = config_.unsynced_hysteresis_sample_count;
     }
```

#### 2c — Fix `classify_wake()` — Add Time Window Guard

This is the **bug fix** for the dusk wake loop. With `unix_time` now available:

```cpp
WakeType DayNightController::classify_wake(
    bool is_gpio_wakeup, uint16_t current_ma, std::optional<time_t> unix_time) const
{
    if (unix_time.has_value()) {
        auto [hour, minute, day_of_year] = decompose(*unix_time);
        SolarDayInfo day_info = calculate_solar_day(day_of_year);
        float current_time = static_cast<float>(hour) + (static_cast<float>(minute) / 60.0f);

        // Dawn window: from 30 min before calculated sunrise until noon
        float dawn_window_start = day_info.sunrise_hour_local - 0.5f;
        bool in_dawn_window = (current_time >= dawn_window_start && current_time < 12.0f);

        if (is_gpio_wakeup) {
            // GPIO outside the dawn window is dusk/night noise -> go back to sleep
            return in_dawn_window ? WakeType::DAWN_GPIO : WakeType::SPURIOUS_TIMER;
        }
        if (in_dawn_window && current_ma >= config_.dawn_current_threshold_ma) {
            return WakeType::DAWN_TIMER;
        }
        if (hour == config_.calibration_wake_hour) {
            return WakeType::CALIBRATION_TIMER;
        }
        return WakeType::SPURIOUS_TIMER;
    }

    // No time sync: fall back to current-only heuristic
    if (is_gpio_wakeup && current_ma >= config_.dawn_current_threshold_ma) {
        return WakeType::DAWN_GPIO;
    }
    if (current_ma >= config_.dawn_current_threshold_ma) {
        return WakeType::DAWN_TIMER;
    }
    return WakeType::SPURIOUS_TIMER;
}
```

Similarly update `calculate_night_sleep_time_us()` to use `decompose()` internally.

---

#### [MODIFY] `solar_sensor.cpp` — Eliminate boilerplate

A private helper added to `SolarSensor`:

```cpp
// solar_sensor.hpp (private):
std::optional<time_t> get_synced_time() const;

// solar_sensor.cpp:
std::optional<time_t> SolarSensor::get_synced_time() const
{
    if (!time_manager_.is_synchronized()) {
        return std::nullopt;
    }
    return static_cast<time_t>(time_manager_.get_timestamp_sec());
}
```

The three boilerplate blocks collapse to single lines:

```diff
-    bool is_synced = time_manager_.is_synchronized();
-    uint8_t hour = 0; uint8_t minute = 0; uint16_t day_of_year = 81;
-    if (is_synced) {
-        time_t now = time_manager_.get_timestamp_sec();
-        struct tm timeinfo{};
-        localtime_r(&now, &timeinfo);
-        hour   = static_cast<uint8_t>(timeinfo.tm_hour);
-        minute = static_cast<uint8_t>(timeinfo.tm_min);
-        day_of_year = static_cast<uint16_t>(timeinfo.tm_yday + 1);
-    }
-    process_ina_samples(is_synced, hour, minute, day_of_year);
+    process_ina_samples(get_synced_time());
```

`process_ina_samples` signature becomes:
```diff
-bool SolarSensor::process_ina_samples(bool is_synced, uint8_t hour, uint8_t minute, uint16_t day_of_year)
+bool SolarSensor::process_ina_samples(std::optional<time_t> unix_time)
```

And inside it:
```diff
-    if (day_night_controller_.should_enter_night_mode(
-            sample.isc_current_ma, is_synced, hour, minute, day_of_year)) {
+    if (day_night_controller_.should_enter_night_mode(sample.isc_current_ma, unix_time)) {
```

Same simplification for `enter_deep_sleep()` and `evaluate_boot_mode()`.

---

#### [MODIFY] `test_day_night_controller.cpp`

All existing tests need updating to pass a `std::optional<time_t>` instead of decomposed fields.

```diff
-EXPECT_FALSE(sut_->should_enter_night_mode(0, false, 12, 0, 81));
+EXPECT_FALSE(sut_->should_enter_night_mode(0, std::nullopt));

-EXPECT_FALSE(sut_->should_enter_night_mode(0, true, 12, 0, 81));
+// 12:00 PM UTC on Day 81 (March 22) => construct a time_t for that
+time_t t_noon_day81 = make_test_time(81, 12, 0); // helper
+EXPECT_FALSE(sut_->should_enter_night_mode(0, t_noon_day81));
```

A small test helper `make_test_time(day_of_year, hour, minute)` will be added to the test file to construct deterministic `time_t` values (UTC epoch-based), avoiding any system TZ dependency in the tests.

New tests for the `classify_wake()` bug fix:

```cpp
TEST_F(DayNightControllerTest, ClassifyWakeGpioAtDuskIsTreatedAsSpurious)
{
    // 17:36 local time, sunrise ~06:00, gpio wakeup -> SPURIOUS (not dawn window)
    time_t t_dusk = make_test_time(81, 17, 36);
    WakeType type = sut_->classify_wake(true, 0, t_dusk);
    EXPECT_EQ(type, WakeType::SPURIOUS_TIMER);
}

TEST_F(DayNightControllerTest, ClassifyWakeGpioAtDawnIsAccepted)
{
    // 06:10 local time, sunrise ~06:00, gpio wakeup -> DAWN_GPIO
    time_t t_dawn = make_test_time(81, 6, 10);
    WakeType type = sut_->classify_wake(true, 10, t_dawn);
    EXPECT_EQ(type, WakeType::DAWN_GPIO);
}
```

---

## Summary of Touched Files

| File | Change |
| --- | --- |
| `main/include/ina_sensor_types.hpp` | Replace `DEFAULT_DAWN_WAKEUP_ALERT_LIMIT` → `DEFAULT_DAWN_ALERT_CURRENT_MA` + add `dawn_alert_current_ma` to `InaSensorConfig` |
| `main/include/interfaces/i_ina_sensor_task.hpp` | Update docs reference |
| `main/src/ina_sensor_task.cpp` | Compute raw alert limit from mA + r_shunt at sleep time |
| `main/include/day_night_controller.hpp` | New signatures + `LocalTime` private struct |
| `main/src/day_night_controller.cpp` | New signatures + `decompose()` helper + bug fix in `classify_wake()` |
| `main/include/solar_sensor.hpp` | Add private `get_synced_time()` + update `process_ina_samples` signature |
| `main/src/solar_sensor.cpp` | Remove 3× `localtime_r` blocks; simplify 3 call sites |
| `host_test/test_day_night_controller/main/test_day_night_controller.cpp` | Update all tests + add `make_test_time()` helper + new `classify_wake` tests |
| `host_test/test_ina_sensor_task/main/test_ina_sensor_task.cpp` | Update `prepare_for_sleep` test expectation |

---

## Verification Plan

### Automated Tests

```bash
# DayNightController unit tests
cd host_test/test_day_night_controller
idf.py build && ./build/test_day_night_controller.elf

# InaSensorTask unit tests
cd host_test/test_ina_sensor_task
idf.py build && ./build/test_ina_sensor_task.elf

# Full host test suite
cd host_test
ctest --output-on-failure

# ESP32 target build
cd test_apps/test_build
idf.py build
```

### Manual Verification

After the next field deployment:
- `Entering deep sleep for X min` log should appear at dusk **once** and the node should stay in sleep until ~06:00.
- No more alternating `Night: YES / Night: NO` in the hub logs at sunset.
- The log `Evaluated boot mode: DAWN_GPIO` should only appear in the early morning window.

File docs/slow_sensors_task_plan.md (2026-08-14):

# Implementation Plan: `SlowSensorsTask`

**Component:** `main/`
**Target:** ESP32-C3 (XIAO)
**Date:** 2026-08-13

---

## 1. Context & Motivation

### Current Situation

| Sensor | Where read | Frequency | Problem |
|---|---|---|---|
| Battery (ADC) | `SolarSensor::update_battery_snapshot()` | Every `run()` tick (~100 ms) | 16x ADC samples x 1 ms delay = ~16 ms blocking `main` per tick |
| DS18B20 (1-Wire) | Not integrated yet | — | 800 ms `vTaskDelay` at 12-bit resolution would stall `main` entirely |

### Goal

Create a single dedicated FreeRTOS task — `SlowSensorsTask` — that:
- Coordinates periodic sampling (every 60 s) of **Battery** and **DS18B20 Temperature**.
- Receives `IBatteryMonitor&` and `IDs18b20Driver&` via constructor Dependency Injection (pure abstract interfaces).
- Publishes results directly into `TelemetrySnapshot` (thread-safe, mutex-protected).
- Completely decouples slow I/O and blocking delays from the `SolarSensor` main loop.

---

## 2. Architecture & Design Decisions

### 2.1 Pure Dependency Injection & Composition Root
`SlowSensorsTask` depends **only** on the abstract interfaces:
- `battery_monitor::IBatteryMonitor&`
- `ds18b20::IDs18b20Driver&`
- `idf_hals::IHalFreertos&`
- `TelemetrySnapshot&`

All hardware pinouts, dividers, and resolution configs stay in `main.cpp` (the Composition Root) where drivers are constructed.

### 2.2 Minimal `SlowSensorsConfig`
Because sensor configurations are handled by their respective drivers, `SlowSensorsConfig` contains only task scheduling parameters:
```cpp
struct SlowSensorsConfig {
    uint32_t sample_interval_ms{60000};  ///< Sampling period in ms (nominal 1 minute)
    uint32_t task_stack_size{3072};      ///< FreeRTOS task stack size in bytes
    uint8_t task_priority{2};            ///< FreeRTOS task priority
    uint8_t max_consecutive_errors{5};   ///< Threshold for error escalation
};
```

### 2.3 `TelemetrySnapshot` as Single Source of Truth
```
SlowSensorsTask  -->  snapshot_.update_battery()
                 -->  snapshot_.update_temperature()
InaSensorTask    <--  snapshot_.get()
SolarSensor      <--  snapshot_.get() (e.g. for NVS persistence)
```

---

## 3. Task Execution Flow

```
SlowSensorsTask::task_loop()
│
├── [on start] bat_monitor_.init()
│              ds18b20_.init()
│
└── loop forever:
    │
    ├── [1] bat_monitor_.read(reading)            ← ~16 ms (fast, performed first)
    │         └── snapshot_.update_battery(reading.voltage_mv, reading.percent, state)
    │
    ├── [2] ds18b20_.read_temperature(&temp_c)    ← ~800 ms (blocks task, NOT main)
    │         └── snapshot_.update_temperature(temp_c)
    │
    ├── [on error] log warning + increment consecutive error counters
    │
    └── [3] vTaskDelay(pdMS_TO_TICKS(interval_ms - elapsed_ms))
```

---

## 4. File Changes

### 4.1 New Files
- `main/include/interfaces/i_slow_sensors_task.hpp`: Abstract lifecycle interface (`init()`, `start()`, `stop()`).
- `main/include/slow_sensors_task.hpp`: Concrete class declaration and `SlowSensorsConfig`.
- `main/src/slow_sensors_task.cpp`: FreeRTOS task implementation loop.

### 4.2 Modified Files
- `main/include/telemetry_snapshot.hpp`: Add `float temperature_celsius{-127.0f}` and `update_temperature(float)`.
- `main/include/solar_sensor.hpp`: Replace `battery_monitor::IBatteryMonitor&` with `ISlowSensorsTask&`.
- `main/src/solar_sensor.cpp`: Remove `update_battery_snapshot()`; initialize `slow_sensors_task_`; extract battery from snapshot in `save_persistent_state()`.
- `main/main.cpp`: Instantiate `ds18b20::OnewireBusHAL`, `ds18b20::Ds18b20Driver`, and `SlowSensorsTask`; inject `SlowSensorsTask` into `SolarSensor`.
- `main/CMakeLists.txt`: Add `slow_sensors_task.cpp` to `SRCS` and `ds18b20_driver` to `REQUIRES`.

---

## 5. Proposed Interfaces

### `ISlowSensorsTask`
```cpp
// main/include/interfaces/i_slow_sensors_task.hpp
#pragma once
#include "esp_err.h"

class ISlowSensorsTask
{
public:
    virtual ~ISlowSensorsTask() = default;

    /**
     * @brief Initializes the battery monitor and DS18B20 drivers.
     * @return ESP_OK on success, ESP_ERR_* on driver failure.
     */
    virtual esp_err_t init() = 0;

    /**
     * @brief Launches the FreeRTOS worker task.
     * @return ESP_OK on success, ESP_ERR_NO_MEM on task creation failure.
     */
    virtual esp_err_t start() = 0;

    /**
     * @brief Stops the FreeRTOS task and releases task handles.
     */
    virtual void stop() = 0;
};
```

---

## 6. Implementation Steps

1. **Update `TelemetrySnapshot`**: Add `temperature_celsius` and `update_temperature()`.
2. **Create `ISlowSensorsTask` Interface**: Save in `main/include/interfaces/i_slow_sensors_task.hpp`.
3. **Implement `SlowSensorsTask`**: In `main/include/slow_sensors_task.hpp` and `main/src/slow_sensors_task.cpp`.
4. **Refactor `SolarSensor`**: Remove direct battery monitor dependency; delegate slow sensing to `ISlowSensorsTask`.
5. **Update `main.cpp`**: Construct DS18B20 driver and `SlowSensorsTask`, pass dependencies into `SolarSensor`.
6. **Update `main/CMakeLists.txt`**: Register component dependencies.
7. **Validate Builds & Tests**:
   - `idf.py build` for ESP32-C3.
   - Run host tests to ensure 0 regressions.

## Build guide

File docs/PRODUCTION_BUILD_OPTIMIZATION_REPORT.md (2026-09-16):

# Production Build Optimization Report via `sdkconfig` (ESP-IDF / ESP32-C3)

---

## Quick Start: How to Build for Production & Development

### 1. Build for Development / Testing (Default Profile)
Running standard `idf.py build` automatically uses `sdkconfig.defaults.dev` (with `INFO` logs, `-Og` debug optimization, and console output enabled):
```bash
source $HOME/dev/esp/esp-idf/export.sh
idf.py build
```

### 2. Build for Production (Field Release)
To build an optimized production binary (silenced `WARN` logs, `-Os` size optimization, silent assertions, no console output):
```bash
source $HOME/dev/esp/esp-idf/export.sh
idf.py -DSDKCONFIG_DEFAULTS="sdkconfig.defaults;sdkconfig.defaults.esp32c3;sdkconfig.defaults.prod" reconfigure build
```
Tip: You may need to clean your build directory, sdconfig and dependencies.lock 
```bash
rm -rf build sdkconfig dependencies.lock
```

---

## 1. Executive Summary

The **Smart Farm Solar Sensor** firmware operates on battery power using a *run-to-completion* design pattern paired with *Deep Sleep*.

In a **Production** environment:
- **Shorter CPU active time = Extended battery lifespan.**
- **Smaller binary image = Faster and safer OTA firmware updates.**
- **Log level reduction = Elimination of UART/USB I/O blocking and reduced Flash footprint.**

This document details optimization recommendations and their performance impact when configuring the build system (`sdkconfig.defaults`) for production releases.

---

## 2. Logging and Console (I/O) Optimizations

### A. Application Default Log Level (`CONFIG_LOG_DEFAULT_LEVEL`)
- **Current State**: `CONFIG_LOG_DEFAULT_LEVEL_INFO=y` (`Level 3 - INFO`).
- **Production Recommendation**: `CONFIG_LOG_DEFAULT_LEVEL_WARN=y` (`Level 2 - WARN`) or `CONFIG_LOG_DEFAULT_LEVEL_ERROR=y` (`Level 1 - ERROR`).
- **Impact**:
  1. **Binary Footprint Reduction**: Removes hundreds of `ESP_LOGI` format string constants from Flash memory.
  2. **Execution Speed**: Eliminates CPU cycles spent formatting strings and transmitting via UART/USB during every wake cycle (~5 ms to ~15 ms saved per cycle).

### B. Bootloader Log Level (`CONFIG_BOOTLOADER_LOG_LEVEL`)
- **Current State**: `CONFIG_BOOTLOADER_LOG_LEVEL_INFO=y` (`Level 3`).
- **Production Recommendation**: `CONFIG_BOOTLOADER_LOG_LEVEL_WARN=y` or `CONFIG_BOOTLOADER_LOG_LEVEL_NONE=y`.
- **Impact**: Reduces Bootloader execution time by approximately **10 ms to 20 ms** on every CPU reset (deep sleep wakeup).

### C. Console Output (`CONFIG_ESP_CONSOLE_DEV_NUM` / `CONFIG_ESP_CONSOLE_NONE`)
- **Current State**: `CONFIG_ESP_CONSOLE_USB_SERIAL_JTAG=y`.
- **Production Recommendation**: If field devices do not require physical USB-Serial console debugging, set `CONFIG_ESP_CONSOLE_NONE=y` or disable log colors (`CONFIG_LOG_COLORS=n`).
- **Impact**: Prevents CPU execution stalls when attempting to transmit over USB-Serial JTAG when no host PC is connected.

---

## 3. Compiler and Binary Size Optimizations

### A. GCC Optimization Level (`CONFIG_COMPILER_OPTIMIZATION`)
- **Current State**: `CONFIG_COMPILER_OPTIMIZATION_DEBUG=y` (`-Og`).
- **Production Recommendation**: `CONFIG_COMPILER_OPTIMIZATION_SIZE=y` (`-Os`).
- **Impact**:
  - Enables aggressive GCC code size optimizations.
  - Reduces the `.bin` firmware image size by **20% to 35%**.
  - Improves ESP32-C3 I-Cache efficiency and reduces OTA download transfer time over Wi-Fi.

### B. Assertion Handling (`CONFIG_COMPILER_OPTIMIZATION_ASSERTIONS`)
- **Current State**: `CONFIG_COMPILER_OPTIMIZATION_ASSERTIONS_ENABLE=y`.
- **Production Recommendation**: `CONFIG_COMPILER_OPTIMIZATION_ASSERTIONS_SILENT=y`.
- **Impact**: Preserves system safety (resets the CPU on assertion failure) while **stripping text filenames and line numbers**, saving Flash memory without compromising runtime safety.

---

## 4. PHY Radio and Power Optimizations

### A. Wi-Fi / ESP-NOW Maximum TX Power (`CONFIG_ESP_PHY_MAX_TX_POWER`)
- **Production Recommendation**: Consider lowering maximum PHY radio transmit power from default 20 dBm to ~15–17 dBm (e.g. `CONFIG_ESP_PHY_MAX_TX_POWER=72`).
- **Impact**:
  - Peak radio transmission current drops from **~340 mA to ~190 mA**.
  - Significantly extends battery health and capacity for nodes located within close/medium range of the Hub.

### B. Serial Flash Access Mode (`CONFIG_ESPTOOLPY_FLASHMODE`)
- **Production Recommendation**: If the target hardware board supports 4 data lines (Quad SPI), configure `CONFIG_ESPTOOLPY_FLASHMODE_QIO=y` at 80 MHz instead of Dual I/O (`DIO`).
- **Impact**: Doubles Flash fetch throughput during code execution, reducing total active uptime prior to entering Deep Sleep.

---

## 5. Security and OTA Production Settings

### A. Disable Insecure HTTP Support
- **Current State**: `CONFIG_ESP_HTTPS_OTA_ALLOW_HTTP=y`.
- **Production Recommendation**: Set `CONFIG_ESP_HTTPS_OTA_ALLOW_HTTP=n` (enforce HTTPS once migrating to production cloud/server infrastructure).

---

## 6. Recommended `sdkconfig.defaults.production` Profile

```ini
# =============================================================================
# Production Build Defaults - Smart Farm Solar Sensor
# =============================================================================

# 1. Compiler Optimization for Size (-Os)
CONFIG_COMPILER_OPTIMIZATION_SIZE=y
# CONFIG_COMPILER_OPTIMIZATION_DEBUG is not set
CONFIG_COMPILER_OPTIMIZATION_ASSERTIONS_SILENT=y

# 2. Logging Optimization (WARN Level & Silence Bootloader)
CONFIG_LOG_DEFAULT_LEVEL_WARN=y
# CONFIG_LOG_DEFAULT_LEVEL_INFO is not set
CONFIG_LOG_DEFAULT_LEVEL=2
CONFIG_BOOTLOADER_LOG_LEVEL_WARN=y
# CONFIG_BOOTLOADER_LOG_LEVEL_INFO is not set
CONFIG_BOOTLOADER_LOG_LEVEL=2
CONFIG_LOG_COLORS=n

# 3. System Task & Rollback Settings
CONFIG_BOOTLOADER_APP_ROLLBACK_ENABLE=y
CONFIG_PARTITION_TABLE_CUSTOM=y
CONFIG_ESP_MAIN_TASK_STACK_SIZE=8192

# 4. Target & Flash
CONFIG_IDF_TARGET="esp32c3"
CONFIG_FREERTOS_UNICORE=y
CONFIG_PM_ENABLE=y
```

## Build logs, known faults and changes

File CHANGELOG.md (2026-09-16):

# Changelog

All notable changes to the `smart-farm-solar-sensor` project will be documented in this file.

## [0.1.6] - 2026-09-15

### Fixed
- Added `ensure_communication_ready` with channel recovery loop and retry handling for `send_night_transition_report` on dusk transition and night calibration before entering deep sleep.
- Ensured synchronous Wi-Fi start on boot with 3000 ms timeout (`wifi_.start(3000)`) in `SolarSensor::init_wifi()`.
- Guarded `send_ota_report` with `ensure_communication_ready()` before dispatching OTA status packet.

## [0.1.5] - 2026-08-29

### Changed
- Fixed issue where ISR was not removed before night transition and NVS save.
- Refactored `process_pending_ota` to deinitialize `EspNowManager` prior to OTA download and restore on fallback.
- Removed obsolete `connect_wifi_with_retry` helper in favor of `WiFiManager::connect(timeout, max_attempts)`.
- Removed obsolete `espnow_trigger` dependency and aligned with `CommandHandler` OTA trigger architecture.
- Bumped firmware version to `0.1.5`.

## [0.1.4] - 2026-08-26

### Added
- Extracted `IDayNightController` interface (`main/include/interfaces/i_day_night_controller.hpp`) and created `MockDayNightController` for isolated host unit testing.
- Extracted `IOtaController` interface (`main/include/interfaces/i_ota_controller.hpp`) matching the node standard established in `pump-controller`, creating `MockOtaController`.
- Extracted `ICommandHandler` interface (`main/include/interfaces/i_command_handler.hpp`) and created `MockCommandHandler`.
- Injected `IDayNightController`, `IOtaController`, and `ICommandHandler` into `SolarSensor` via Constructor Dependency Injection, achieving 100% DI compliance across all external dependencies.

### Changed
- Integrated `SunSchedule` from `smart-farm-common` into `DayNightController`, delegating astronomical calculations and removing redundant latitude and timezone fields from `DayNightConfig`.
- Decoupled `CommandHandler` from `CoreData`, centralizing core storage state updates (`SYNC_TIME`) within `SolarSensor::handle_command_process_result()`.
- Simplified `test_solar_sensor` test fixtures by leveraging pure interface mocks (`MockOtaController`, `MockDayNightController`, `MockCommandHandler`), eliminating coupling to underlying FreeRTOS byte streams.
- Cleaned up obsolete local mock headers in favor of shared mocks from `smart-farm-common` and `espnow_manager`.
- Bumped firmware version to `0.1.4`.

## [0.1.3] - 2026-08-17

### Changed
- Refactored `SolarSensorNvs` to inherit from the generic `AppStorage<SolarStats, Magic, Version>` CRTP base class in `smart-farm-common`, eliminating local NVS boilerplate and implementation files.
- Decoupled domain struct `SolarStats` from storage metadata (`magic`, `version`, `crc`), wrapping it automatically with the new `StorageEnvelope` pattern.
- Migrated `CoreStorage` usage to pure `CoreData` and separated `process_boot_reasons()` from storage initialization.
- Simplified `init_solar_storage()` and `init_core_storage()` logic utilizing `init_app_data()` / `init()` with automatic fallback to defaults.
- Migrated dedicated NVS unit tests to the generic test suite `test_app_storage` in `smart-farm-common`.
- Bumped firmware version to `0.1.3`.

## [0.1.0] - 2026-08-13

### Added
- Initial firmware release for the Smart Farm Solar Sensor Node based on ESP32-C3.
- High-frequency short-circuit current (Isc) and irradiance measurement via `InaSensorTask` integrating `ina226_driver` with hardware conversion-ready alert synchronization.
- Low-frequency background telemetry worker task (`SlowSensorsTask`) periodically reading battery status (`battery_monitor`) and ambient temperature (`ds18b20_driver`) without blocking the main control loop.
- Thread-safe telemetry snapshot mechanism (`TelemetrySnapshot`) synchronizing sensor data between acquisition tasks and communication loops.
- Real-time ESP-NOW telemetry broadcasting to the central Hub (`farm::SolarSensorReport`).
- Astronomical day/night detection and power management (`DayNightController`) featuring solar declination algorithms, dusk/dawn threshold filtering, and deep sleep scheduling.
- Dual-tier persistence engine (`SolarSensorNvs`) leveraging RTC Fast Memory and Flash NVS with CRC32 integrity checks.
- Reliable day/night power profile handshake: broadcasts final telemetry report with mandatory ESP-NOW ACK before deep sleep and night calibration, allowing Hub to queue downstream commands.
- Post-transmission command draining window (100ms) during night cycles ensuring time synchronization (`SYNC_TIME`) and remote commands are processed and committed prior to deep sleep.
- Dynamic `PowerProfile` synchronization (`ALWAYS_ON` $\leftrightarrow$ `DEEP_SLEEP`) reflected across `CoreStorage` and `TelemetrySnapshot`.
- Remote ESP-NOW command processing (`CommandHandler`) supporting clock synchronization (`SYNC_TIME`), OTA update initiation (`START_OTA`), and remote reboot (`REBOOT`).
- Over-The-Air (OTA) firmware upgrade management and rollback protection (`OtaController`) integrated with `ota_manager`.
- Modular host-based testing architecture with GoogleTest/GoogleMock across 7 dedicated subprojects (66 unit tests).
- Automated GitHub Actions CI pipelines for ESP32-C3 target firmware compilation and host test execution with unified LCOV coverage reporting published to GitHub Pages.

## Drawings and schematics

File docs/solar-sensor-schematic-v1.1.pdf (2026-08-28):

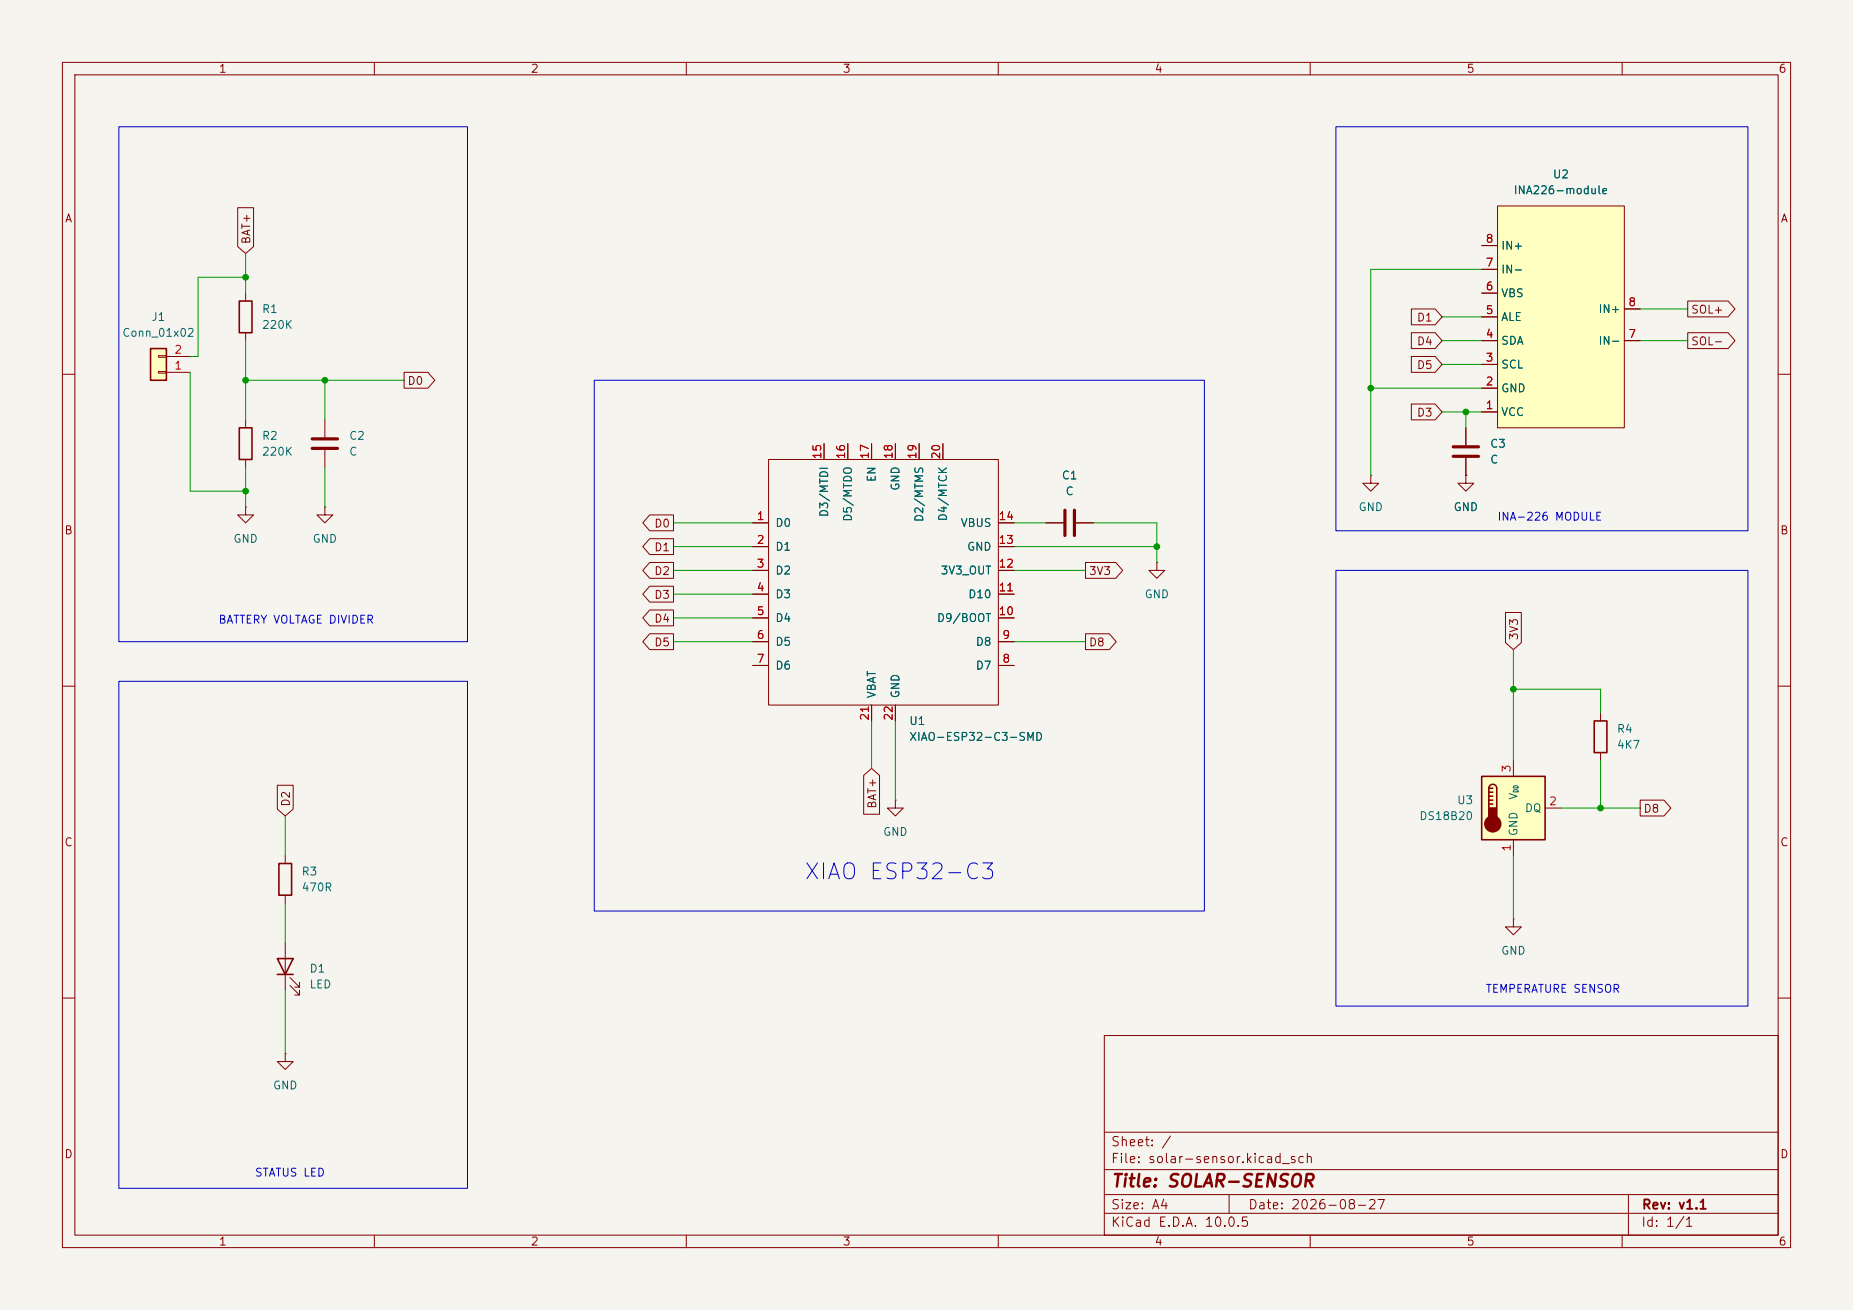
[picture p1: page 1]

Size: A4 | Rev: v1.1
KiCad E.D.A. 10.0.5 | Id: 1/1

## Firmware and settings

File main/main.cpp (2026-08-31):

#include <cstdint>

#define LOG_LOCAL_LEVEL ESP_LOG_INFO
#include "esp_log.h"

#include "hal_timer.hpp"
#include "hal_nvs.hpp"
#include "hal_sys_rom.hpp"
#include "hal_sys_rom.hpp"
#include "hal_adc_oneshot.hpp"
#include "hal_adc_calibration.hpp"
#include "hal_gpio.hpp"
#include "hal_freertos.hpp"
#include "hal_sleep.hpp"
#include "hal_system.hpp"
#include "hal_system_time.hpp"
#include "hal_sntp.hpp"

#include "solar_sensor.hpp"
#include "farm_protocol_types.hpp"
#include "persistence_backend.hpp"
#include "nvs_core.hpp"
#include "solar_sensor_nvs.hpp"
#include "battery_monitor.hpp"
#include "adc_battery_reader.hpp"
#include "ota_manager.hpp"
#include "ota_controller.hpp"
#include "button_ota_trigger.hpp"
#include "espnow_manager.hpp"
#include "wifi_manager.hpp"
#include "time_manager.hpp"

#include "hal_i2c.hpp"
#include "ina226_driver.hpp"
#include "ina_sensor_task.hpp"
#include "ds18b20_driver.hpp"
#include "hal_onewire_bus.hpp"
#include "slow_sensors_task.hpp"
#include "telemetry_snapshot.hpp"
#include "led_controller.hpp"
#include "sun_schedule.hpp"
#include "day_night_controller.hpp"
#include "command_handler.hpp"

#include "secrets.hpp"

#include "freertos/ringbuf.h"
#include "lwip/sockets.h"

static const char* TAG = "main";

static constexpr bool IS_LOGGING = false;

static constexpr const char* CORE_NVS_KEY = "core";
static constexpr const char* STATS_NVS_KEY = "solar_stats";

// HAL instances for sharing across components
static idf_hals::TimerHAL hal_timer;
static idf_hals::NvsHAL nvs_hal;
static idf_hals::SysRomHAL hal_sys_rom;
static idf_hals::HalAdcOneshot hal_oneshot;  // Batery monitor ADC
static idf_hals::HalAdcCalibration hal_cali; // Batery monitor ADC
static idf_hals::GpioHAL hal_gpio;
static idf_hals::I2cHAL hal_i2c;
static idf_hals::HalFreertos hal_freertos;
static idf_hals::SleepHAL hal_sleep;
static idf_hals::SystemHAL hal_system;
static idf_hals::HalSystemTime hal_sys_time;
static idf_hals::HalSntp hal_sntp;
static ds18b20::OnewireBusHAL hal_onewire;

// INA226 Driver
// The daytime regime is the default: build the driver with the day conversion
// settings so init() applies them on every boot (and after INA recovery).
// InaSensorTask::init() arms the conversion-ready alert (CNVR); the night
// regime is applied only by InaSensorTask::prepare_for_sleep().
static constexpr ina226::Ina226Config ina_day_config = {
    .r_shunt_ohms = 0.1f,
    .avg_mode = ina226::AveragingMode::AVG_64,
    .vbus_ct = ina226::ConversionTime::CT_1100US,
    .vsh_ct = ina226::ConversionTime::CT_1100US,
    .mode = ina226::OperatingMode::SHUNT_AND_BUS_CONTINUOUS};

static ina226::Ina226Driver ina_driver{hal_i2c, ina_day_config};

// BatteryMonitor
static battery_monitor::BatteryAdcConfig adc_config = {
    .gpio_num = static_cast<int>(BATTERY_LEVEL_GPIO),
    .sample_count = 16,
    .sample_delay_us = 1000,
    .enable_calibration = true};

static battery_monitor::BatteryMonitorConfig monitor_config = {
    .divider_top_ohms = 240000,
    .divider_bottom_ohms = 240000};

static battery_monitor::AdcBatteryReader adc_reader{hal_oneshot, hal_cali, hal_sys_rom, adc_config};
static battery_monitor::BatteryMonitor bat_monitor{adc_reader, monitor_config};

// DS18B20 1-Wire Driver
static ds18b20::Ds18b20Config ds18b20_config{
    .gpio_num = static_cast<int>(DS18B20_GPIO),
    .max_rx_bytes = 10,
    .enable_pullup = true,
    .initial_resolution = ds18b20::Resolution::BITS_12,
};
static ds18b20::Ds18b20Driver ds18b20_driver{hal_onewire, ds18b20_config};

// Telemetry Snapshot
static TelemetrySnapshot g_telemetry_snapshot;

// SlowSensorsTask (Battery + DS18B20)
static SlowSensorsConfig slow_sensors_config{
    .sample_interval_ms = 60000,
    .task_stack_size = 3072,
    .task_priority = 2,
};
static SlowSensorsTask
    slow_sensors_task{bat_monitor, ds18b20_driver, hal_freertos, g_telemetry_snapshot, slow_sensors_config};

// Persistence and App instantiation
static RTC_DATA_ATTR CoreStorage g_rtc_core;
static RtcBackend rtc_core_backend(&g_rtc_core, sizeof(CoreStorage));
static NvsBackend nvs_core_backend{nvs_hal, CORE_NVS_KEY};
static NvsCore nvs_core{rtc_core_backend, nvs_core_backend};

static RTC_DATA_ATTR SolarStorage g_rtc_stats;
static RtcBackend rtc_stats_backend(&g_rtc_stats, sizeof(SolarStorage));
static NvsBackend nvs_stats_backend{nvs_hal, STATS_NVS_KEY};
static SolarSensorNvs nvs_solar{rtc_stats_backend, nvs_stats_backend};

// OtaManager — HAL implementations
static HttpClient http_client;
static ManifestParser manifest_parser;
static OtaSession ota_session;
static System ota_system;
static TaskScheduler task_scheduler;
static RollbackManager rollback_manager;
static OtaDependencies ota_deps = {
    .http_client = http_client,
    .manifest_parser = manifest_parser,
    .ota_session = ota_session,
    .system = ota_system,
    .task_scheduler = task_scheduler,
    .rollback_manager = rollback_manager,
};
static OtaManager ota_manager(ota_deps);
static OtaController ota_controller(ota_manager, hal_freertos);

// OTA trigger: boot button
static ButtonOtaTrigger btn_trigger(hal_gpio, hal_freertos, BOOT_BUTTON_GPIO, 200);

// Status LED Controller
static LedConfig led_config{
    .gpio_num = STATUS_LED_GPIO,
    .task_stack_size = 2048,
    .task_priority = 1,
    .active_level = 1,
};
static LedController led_controller{hal_gpio, hal_freertos, led_config};

static time_manager::TimeManager time_mgr{hal_sntp, hal_sys_time};

static SunSchedule sun_schedule{LOCATION_LATITUDE_DEG, LOCATION_TZ_OFFSET_HOURS};
static DayNightController day_night_controller{sun_schedule};

extern "C" void app_main()
{
    ESP_LOGW(TAG, "Initializing Smart Farm Solar Sensor...");

    // Create ESP-NOW receive queue & INA sample queue
    QueueHandle_t rx_queue = hal_freertos.queue_create(30, sizeof(espnow::AppMessage));
    QueueHandle_t ina_sample_queue = hal_freertos.queue_create(10, sizeof(InaSample));

    // Retrieve singleton references for DI
    auto& wifi = wifi_manager::WiFiManager::get_instance();
    auto& espnow = espnow::EspNowManager::instance();

    // Instantiate INA Sensor Task (power control managed by the app, not the task)
    static ina::InaSensorTask ina_task{
        ina_driver, espnow, hal_timer, hal_freertos, time_mgr, g_telemetry_snapshot, ina_sample_queue};

    // Instantiate CommandHandler
    static CommandHandler command_handler{rx_queue, espnow, time_mgr, hal_freertos};

    // Instantiate app with dependencies
    static SolarSensor solar(
        ina_task,
        ina_sample_queue,
        g_telemetry_snapshot,
        slow_sensors_task,
        nvs_core,
        nvs_solar,
        hal_timer,
        ota_controller,
        btn_trigger,
        espnow,
        rx_queue,
        wifi,
        hal_sleep,
        hal_system,
        time_mgr,
        hal_freertos,
        hal_gpio,
        hal_i2c,
        led_controller,
        day_night_controller,
        command_handler);

    // Initialize application state
    solar.init();

    // Run the main application flow in a loop while active
    while (solar.run()) {
        hal_freertos.task_delay(pdMS_TO_TICKS(100));
    }
}

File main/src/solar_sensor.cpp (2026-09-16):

#define LOG_LOCAL_LEVEL ESP_LOG_INFO
#include "esp_log.h"

#include "solar_sensor.hpp"

#include <algorithm>
#include <cmath>

#include "esp_intr_alloc.h"

#include "secrets.hpp"
#include "ina_sensor_types.hpp"

static const char* TAG = "SolarSensor";

static constexpr uint16_t DEEP_SLEEP_TIME_MIN = 60;

static constexpr uint32_t SINGLE_PASS_TIMEOUT_MS =
    espnow::SCAN_CHANNEL_TIMEOUT_MS * espnow::SCAN_CHANNEL_ATTEMPTS * 13 + 200;

// ============== INA226 Config ==============
// The daytime regime is the default and lives in the Ina226Driver construction
// (main.cpp); InaSensorTask::init() arms the conversion-ready alert (CNVR).
// Only the night (sleep) conversion settings are overridden here.
static constexpr InaSensorConfig ina_config = {
    .delta_threshold_ma = 10,
    .delta_threshold_percent = 0.03f,
    .heartbeat_interval_ms = 5000,
    .night_config =
        {
            .vsh_ct = ina226::ConversionTime::CT_8244US,
            .vbus_ct = ina226::ConversionTime::CT_8244US,
            .avg_mode = ina226::AveragingMode::AVG_1024,
        },
};

SolarSensor::SolarSensor(
    ina::IInaSensorTask& ina_sensor_task,
    QueueHandle_t ina_sample_queue,
    TelemetrySnapshot& telemetry_snapshot,
    ISlowSensorsTask& slow_sensors_task,
    INvsCore& core_storage,
    ISolarSensorNvs& solar_storage,
    idf_hals::ITimerHAL& hal_timer,
    IOtaController& ota_controller,
    IOtaTrigger& btn_trigger,
    espnow::IEspNowManager& espnow,
    QueueHandle_t rx_queue_,
    wifi_manager::IWiFiManager& wifi,
    idf_hals::ISleepHAL& hal_sleep,
    idf_hals::ISystemHAL& hal_system,
    time_manager::ITimeManager& time_manager,
    idf_hals::IHalFreertos& hal_freertos,
    idf_hals::IGpioHAL& hal_gpio,
    idf_hals::II2cHAL& hal_i2c,
    ILedController& led,
    IDayNightController& day_night_controller,
    ICommandHandler& command_handler)
    : ina_sensor_task_(ina_sensor_task)
    , ina_sample_queue_(ina_sample_queue)
    , telemetry_snapshot_(telemetry_snapshot)
    , slow_sensors_task_(slow_sensors_task)
    , core_storage_(core_storage)
    , solar_storage_(solar_storage)
    , hal_timer_(hal_timer)
    , ota_controller_(ota_controller)
    , btn_trigger_(btn_trigger)
    , espnow_(espnow)
    , rx_queue_(rx_queue_)
    , wifi_(wifi)
    , hal_sleep_(hal_sleep)
    , hal_system_(hal_system)
    , time_manager_(time_manager)
    , hal_rtos_(hal_freertos)
    , hal_gpio_(hal_gpio)
    , hal_i2c_(hal_i2c)
    , led_(led)
    , day_night_controller_(day_night_controller)
    , command_handler_(command_handler)
{
}

SolarSensor::~SolarSensor()
{
    hal_gpio_.isr_handler_remove(INA_ALERT_GPIO);
    ina_task_handle_ = nullptr;
}

esp_err_t SolarSensor::init()
{
    esp_err_t err;

    // 0. Initialize and start Status LED Controller
    if ((err = led_.init()) != ESP_OK) {
        ESP_LOGW(TAG, "Failed to initialize LedController: %s", esp_err_to_name(err));
    }
    led_.start();

    // Arm OTA triggers
    btn_trigger_.arm(*this);

    // 1. Initialize OtaController
    OtaConfig ota_config{
        .device_type = "solar_sensor",
        .manifest_url = SERVER_URL,
        .task_stack_size = 8192,
        .task_priority = 5,
        .transport = {.manifest_timeout_ms = 3000, .firmware_timeout_ms = 30000},
        .security = {.allow_http_during_development = true},
        .allow_same_version = false,
        .restart_on_success = false,
    };

    if (!ota_controller_.init(ota_config)) {
        ESP_LOGW(TAG, "Failed to initialize OtaController config");
        led_.set_pattern(BlinkPattern::ERROR_BURST);
        return ESP_FAIL;
    }

    // 2. Wifi for esp-now and OTA
    if ((err = init_wifi()) != ESP_OK) {
        ESP_LOGE(TAG, "Failed to initialize WiFi: %s", esp_err_to_name(err));
        session_healthy_ = false;
    }

    if ((err = init_time()) != ESP_OK) {
        ESP_LOGE(TAG, "Failed to initialize TimeManager: %s", esp_err_to_name(err));
        session_healthy_ = false;
    }

    // 3. Initialize storage
    if ((err = init_core_storage()) != ESP_OK) {
        ESP_LOGE(TAG, "Failed to initialize core storage: %s", esp_err_to_name(err));
        session_healthy_ = false;
    }
    if ((err = init_solar_storage()) != ESP_OK) {
        ESP_LOGE(TAG, "Failed to initialize solar storage: %s", esp_err_to_name(err));
        session_healthy_ = false;
    }
    update_running_version();

    // 5. Initialize and start SlowSensorsTask (Battery + DS18B20)
    if ((err = slow_sensors_task_.init()) != ESP_OK) {
        ESP_LOGE(TAG, "Failed to initialize SlowSensorsTask: %s", esp_err_to_name(err));
        session_healthy_ = false;
    }
    if ((err = slow_sensors_task_.start()) != ESP_OK) {
        ESP_LOGE(TAG, "Failed to start SlowSensorsTask: %s", esp_err_to_name(err));
        session_healthy_ = false;
    }

    // 6. Initialize esp-now
    if ((err = init_espnow()) != ESP_OK) {
        ESP_LOGE(TAG, "Failed to initialize esp-now: %s", esp_err_to_name(err));
        session_healthy_ = false;
    }

    // 7. Initialize INA VCC pin
    if ((err = init_ina_vcc_pin()) != ESP_OK) {
        ESP_LOGE(TAG, "Failed to initialize INA VCC pin: %s", esp_err_to_name(err));
        session_healthy_ = false;
    }

    // 8. Initialize INA task
    if ((err = init_ina_task(ina_config)) != ESP_OK) {
        ESP_LOGE(TAG, "Failed to initialize INA Sensor Task: %s", esp_err_to_name(err));
        session_healthy_ = false;
    }

    // 9. Attach the INA ALERT GPIO ISR
    if ((err = init_ina_alert_pin()) != ESP_OK) {
        ESP_LOGE(TAG, "Failed to initialize INA alert pin: %s", esp_err_to_name(err));
        session_healthy_ = false;
    }

    // 10. Perform post-boot firmware verification
    if (!is_firmware_healthy(session_healthy_)) {
        session_healthy_ = false;
    }

    if (!session_healthy_) {
        ESP_LOGE(TAG, "SolarSensor session not healthy during boot initialization");
        led_.set_pattern(BlinkPattern::ERROR_BURST);
        return ESP_FAIL;
    }

    led_.set_pattern(BlinkPattern::BOOT_SUCCESS);
    ESP_LOGI(TAG, "SolarSensor initialized");
    return ESP_OK;
}

bool SolarSensor::run()
{
    if (!wake_classified_) {
        wake_classified_ = true;
        WakeType wake = evaluate_boot_mode();

        if (wake == WakeType::CALIBRATION_TIMER) {
            process_night_calibration();
            return false;
        }
        if (wake == WakeType::SPURIOUS_TIMER) {
            process_spurious_wake();
            return false;
        }

        on_dawn_start();
    }

    return run_day_cycle();
}
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

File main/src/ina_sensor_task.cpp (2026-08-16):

// main/src/ina_sensor_task.cpp
#include "ina_sensor_task.hpp"

#include <algorithm>
#include <cmath>

#define LOG_LOCAL_LEVEL ESP_LOG_INFO
#include "esp_log.h"
#include "farm_protocol_types.hpp"

static const char* TAG = "InaSensorTask";

namespace ina {

InaSensorTask::InaSensorTask(
    ina226::IIna226Driver& driver,
    espnow::IEspNowManager& espnow,
    idf_hals::ITimerHAL& timer,
    idf_hals::IHalFreertos& rtos,
    time_manager::ITimeManager& time_manager,
    TelemetrySnapshot& snapshot,
    QueueHandle_t sample_queue)
    : driver_(driver)
    , espnow_(espnow)
    , timer_(timer)
    , rtos_(rtos)
    , time_manager_(time_manager)
    , snapshot_(snapshot)
    , sample_queue_(sample_queue)
{
}

InaSensorTask::~InaSensorTask()
{
    deinit();
}

esp_err_t InaSensorTask::init(const InaSensorConfig& config, i2c_master_bus_handle_t i2c_bus)
{
    config_ = config;

    esp_err_t err = driver_.init(i2c_bus);
    if (err != ESP_OK) {
        ESP_LOGE(TAG, "Failed to initialize INA226 driver: %s", esp_err_to_name(err));
        return err;
    }

    // Daytime regime: arm ALERT_ON_CONVERSION_READY (CNVR, bit 10) — the only
    // conversion-complete flag that asserts the ALERT pin, so the GPIO ISR
    // wakes the task on every completed conversion. The alert limit is unused
    // for CNVR. prepare_for_sleep() re-arms the pin for the dawn wakeup.
    err = driver_.configure_alert(static_cast<uint16_t>(ina226::AlertFlag::ALERT_ON_CONVERSION_READY), 0);
    if (err != ESP_OK) {
        ESP_LOGE(TAG, "Failed to configure conversion-ready alert: %s", esp_err_to_name(err));
        return err;
    }

    last_report_timestamp_us_ = timer_.get_time_us();
    float r_shunt = driver_.get_config().r_shunt_ohms;
    uv_per_ma_ = (r_shunt > 0.0f) ? (r_shunt * 1000.0f) : 100.0f;
    ESP_LOGI(TAG, "InaSensorTask initialized successfully (R_shunt=%.3f Ohm, uV_per_mA=%.1f)", r_shunt, uv_per_ma_);

    if (task_handle_ == nullptr) {
        running_.store(true);
        task_done_semaphore_ = rtos_.semaphore_create_binary();
        if (task_done_semaphore_ == nullptr) {
            return ESP_ERR_NO_MEM;
        }

        BaseType_t task_ret = rtos_.task_create(
            task_entry_point, "InaSensorTask", config_.task_stack_size, this, config_.task_priority, &task_handle_);

        if (task_ret != pdPASS) {
            ESP_LOGE(TAG, "Failed to create INA Sensor Task");
            rtos_.semaphore_delete(task_done_semaphore_);
            task_done_semaphore_ = nullptr;
            running_.store(false);
            return ESP_ERR_NO_MEM;
        }
    }

    initialized_ = true;
    return ESP_OK;
}

esp_err_t InaSensorTask::start()
{
    sampling_enabled_.store(true);
    reporting_enabled_.store(true);
    return ESP_OK;
}

void InaSensorTask::stop()
{
    sampling_enabled_.store(false);
    reporting_enabled_.store(false);
}

esp_err_t InaSensorTask::deinit()
{
    stop();

    if (task_handle_ != nullptr) {
        running_.store(false);
        rtos_.task_notify_give(task_handle_);
        // Wait for task to exit
        uint8_t delay_ms = 10;
        for (int timeout = 1000; timeout > 0; timeout -= delay_ms) {
            if (rtos_.semaphore_take(task_done_semaphore_, delay_ms) == pdPASS)
                break;
        }

        // Forcing deleting task if timeout occurred
        if (task_handle_ != nullptr) {
            ESP_LOGW(TAG, "Forcing deletion of INA sensor task");
            rtos_.task_delete(task_handle_);
            task_handle_ = nullptr;
        }
    }
    if (task_done_semaphore_ != nullptr) {
        rtos_.semaphore_delete(task_done_semaphore_);
        task_done_semaphore_ = nullptr;
    }

    if (initialized_) {
        initialized_ = false;
        return driver_.deinit();
    }

    return ESP_OK;
}

esp_err_t InaSensorTask::prepare_for_sleep()
{
    // Stop producing samples and reports: the app is about to enter deep sleep.
    stop();

    // Slow down the conversions to cut power consumption for the night regime.
    esp_err_t err = apply_night_config(config_.night_config);
    if (err != ESP_OK) {
        ESP_LOGE(TAG, "Failed to apply night conversion config: %s", esp_err_to_name(err));
        return err;
    }

    // Arm the dawn wakeup alert: SHUNT_OVER_VOLTAGE asserts the ALERT pin when
    // the panel current rises above config_.dawn_alert_current_ma, waking the
    // MCU from deep sleep via the GPIO.
    // INA226 Shunt Voltage LSB is 2.5 uV per LSB.
    float v_shunt_uv = static_cast<float>(config_.dawn_alert_current_ma) * uv_per_ma_;
    uint16_t alert_limit = static_cast<uint16_t>(v_shunt_uv / 2.5f);

    err = driver_.configure_alert(
        static_cast<uint16_t>(ina226::AlertFlag::SHUNT_OVER_VOLTAGE), alert_limit);
    if (err != ESP_OK) {
        ESP_LOGE(TAG, "Failed to configure dawn wakeup alert: %s", esp_err_to_name(err));
        return err;
    }

    // Acknowledge/clear any pending alert flags to ensure ALERT pin is deasserted (HIGH)
    uint16_t alert_flags = 0;
    driver_.read_alert_flags(alert_flags);

    ESP_LOGI(
        TAG,
        "InaSensorTask prepared for sleep (avg=%u, vbus=%luus, vsh=%luus, alert=SHUNT_OVER_VOLTAGE, limit=%u raw / %u mA)",
        static_cast<unsigned>(ina226::averaging_mode_to_count(config_.night_config.avg_mode)),
        static_cast<unsigned long>(ina226::conversion_time_to_us(config_.night_config.vbus_ct)),
        static_cast<unsigned long>(ina226::conversion_time_to_us(config_.night_config.vsh_ct)),
        alert_limit,
        config_.dawn_alert_current_ma);
    return ESP_OK;
}

uint32_t InaSensorTask::get_expected_sample_period_ms() const
{
    // The period depends on the conversion settings currently active on the
    // hardware, which the driver owns. During normal (day) operation this is
    // the day config applied at init; after prepare_for_sleep() it reflects
    // the slower night regime.
    const ina226::Ina226Config& hw_cfg = driver_.get_config();

    uint32_t vsh_us = ina226::conversion_time_to_us(hw_cfg.vsh_ct);
    uint32_t vbus_us = ina226::conversion_time_to_us(hw_cfg.vbus_ct);
    uint32_t avg_count = ina226::averaging_mode_to_count(hw_cfg.avg_mode);

    return ((vsh_us + vbus_us) * avg_count) / 1000;
}

uint32_t InaSensorTask::get_watchdog_timeout_ms() const
{
    uint32_t period_ms = get_expected_sample_period_ms();
    return std::max<uint32_t>(500, period_ms * 3);
}
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

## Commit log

2026-08-08 first build (error)
    [partitions.csv]
2026-08-08 refactor: fix build and add submodules components as DI
    [main.cpp, solar_sensor.cpp]
2026-08-09 doc: add arquiteture and guidelines to solar sensor
2026-08-09 fix: SolarStats operator== overload
    [solar_sensor_stats.hpp]
2026-08-09 feat(solar-stats): update SolarStats and add unit tests for Stage 2
2026-08-09 feat(ina-task): implement InaSensorTask with unit tests and power control integration
2026-08-09 feat(main): wire I2C bus, PowerControl, Ina226Driver, and InaSensorTask in app_main
2026-08-09 feat(watchdog): add dynamic sample period & daytime-only watchdog timeout
2026-08-09 refactor(ina-task): move power control and error recovery to app layer
    - InaSensorTask loses: power_control_, consecutive_errors_,
    handle_read_error(), hard_reset_ina_power()
    - Task is now a pure reader/publisher: reads INA226, applies EMA,
    enqueues sample (with error status on failure), dispatches telemetry
    - SolarSensor owns PowerControl and is the sole error recovery authority:
    counts consecutive errors via sample.status, restarts on threshold
    - IInaSensorTask interface drops hard_reset_ina_power()
    - init_ina_task() now fully configures day/night InaModeConfig profiles
    - Host tests updated: removed mock_power_control_ from fixture,
    replaced ConsecutiveI2cErrorsTriggerHardReset wit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
    [ina_sensor_task.cpp, main.cpp, solar_sensor.cpp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]
2026-08-10 fix(i2c): use C++ value initialization for bus_cfg.clk_source to support both target and host builds
    [ina_sensor_task.cpp, main.cpp, solar_sensor.cpp]
2026-08-10 chore: update submodules fixing i2c errors
2026-08-10 refactor: i2c bus init from main to solar sensor app
2026-08-10 fix(hals): add driver/rtc_io.h fallback guard in i_hal_rtc_gpio.hpp and clean cpp header
    [solar_sensor.cpp]
2026-08-10 feature: implement INA sensor task management and semaphore handling
2026-08-11 refactor: rework InaSensorTask night regime via prepare_for_sleep()
    Replace the day/night operating-mode switch with a single
    prepare_for_sleep() that disables sampling/reporting, applies the
    night conversion settings (slow CT_8244US) and arms the dawn wakeup
    alert. The daytime regime is now the driver default set in main.cpp,
    and init() arms the conversion-ready alert (CNVR) that asserts the
    ALERT pin on every conversion. Sample period and watchdog timeout are
    derived from the active driver config instead of the day/night split.
    Also fix ina_alert_isr_handler to use the canonical
    portYIELD_FROM_ISR(xHigherPriorityTaskWoken) form so the host test
    build passes, and align host mocks/tests wit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
    [ina_sensor_task.cpp, ina_sensor_types.hpp, main.cpp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]
2026-08-11 feat: integrate INA ALERT pin ISR and deep sleep night flow
    Attach the conversion-ready (CNVR) ALERT GPIO ISR during init() so the
    InaSensorTask is notified on every completed conversion, and re-attach
    it after INA hardware recovery (the task is recreated with a new
    handle). The ISR service now registers with ESP_INTR_FLAG_IRAM and the
    alert pin moved to GPIO3 — the only C3 pins that wake from deep sleep
    are GPIO0-5. enter_deep_sleep() arms the night regime via
    prepare_for_sleep() first, aborts if that fails (avoids a wake loop)
    and checks the GPIO wakeup return with the timer as fallback.
    Also bump idf_hals to d1a8c4d for the DEEPSLEEP_WAKEUP macro fix.
    [solar_sensor.cpp]
2026-08-11 feat: integrate TelemetrySnapshot, ITimeManager, and updated BatteryMonitor (Step 1a & 1b)
2026-08-12 feat(solar_sensor): integrate Step 5 run loop, CommandProcessResult, and INA sample processing
2026-08-13 refactor(solar_sensor): modularize boot routing and apply INA zero offset calibration
2026-08-13 refactor(solar_sensor): replace estimated_power_w with panel_temp_c in telemetry report
    [ina_sensor_task.cpp]
2026-08-13 fix(ina_sensor_task): require minimum 20mA threshold for relative percent delta trigger and fix RTC CRC dirty check
    [ina_sensor_task.cpp, solar_sensor.cpp]
2026-08-13 logging(ina_sensor_task): print actual sample count and conversion time in us in prepare_for_sleep log
2026-08-13 feat(solar_sensor): implement median filtering and sanity bounds for lightning-immune night zero calibration
2026-08-13 test(solar_sensor): add unit test for night calibration with lightning spike rejection and median filtering
2026-08-13 test(solar_sensor): provide mock InaSample in RunProcessesOtaTriggerWhenSet to avoid watchdog timeout
    [solar_sensor.cpp, test_solar_sensor.cpp]
2026-08-14 feat: implement SlowSensorsTask integrating battery and DS18B20 temperature sampling
2026-08-14 feat(power): send telemetry report with ACK and sync power profile before deep sleep
2026-08-14 feat(led): add LedController, update pinout map, and enhance state machine
2026-08-14 test(solar_sensor): fix mock sample indexing in night calibration test
    [test_solar_sensor.cpp]
2026-08-14 chore: remove unused power_control submodule
2026-08-14 chore: remove power_control component references from CMakeLists
2026-08-15 fix(solar-sensor): refactor InaSensorTask lifecycle and fix night sleep transitions
    [day_night_controller.cpp, ina_sensor_task.cpp, solar_sensor.cpp]
2026-08-15 fix: LedController initialization
2026-08-15 refactor(ota): return OtaVerifyResult from OtaController::execute_download
    - Replace OtaDownloadResult with unified OtaVerifyResult in execute_download()
    - Automatically populate running firmware version and exec_result from OtaManager
    - Update SolarSensor OTA failure path to record running version into core_ and report
    - Update host unit tests for OtaController
    [ota_controller.cpp, solar_sensor.cpp]
2026-08-15 refactor(day_night): migrate to unix_time API, configure INA alert in mA, and fix dusk wake loop
    [day_night_controller.cpp, ina_sensor_task.cpp, ina_sensor_types.hpp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]
2026-08-16 docs: add circuit schematic svg and embed in README
2026-08-18 refactor: use led controller from common and delete local files and tests
2026-08-18 refactor(ota): decouple running version and split verification checks in OtaController
    - Replace OtaVerifyResult with streamlined OtaActionResult
    - Add dedicated check_pending_verify() and get_running_version() queries
    - Add confirm_firmware() command for explicit post-OTA boot evaluation
    - Sincronize running version into CoreData after storage initialization in SolarSensor
    - Update and extend unit test suite in test_ota_controller
    [ota_controller.cpp, solar_sensor.cpp]
2026-08-18 chore: update ds18b20 drivers ubmodule
2026-08-27 refactor(espnow): update EspNowConfig for v1.5.0 and remove obsolete check_espnow_connection
    - Remove obsolete check_espnow_connection method, interval constant, and member variable
    - Configure EspNowConfig with heartbeat_interval_ms (30s), enable_heartbeat (false), logical_ack_retries (2), ack_timeout_ms (350)
    - Update INA sensor baseline reporting interval to 5000ms
    - Remove duplicate local mocks in favor of component provided mocks
    - Update host test cases and verify all tests pass (75/75)
2026-08-27 refactor(day_night): extract IDayNightController interface and use SunSchedule
    - Create IDayNightController interface and mock for host tests
    - Refactor DayNightController to implement IDayNightController and depend on SunSchedule
    - Remove duplicated Cooper solar calculation and geographical fields from DayNightConfig
    - Inject IDayNightController into SolarSensor via constructor DI
    - Update host test fixtures and verify all tests pass
    [day_night_controller.cpp, main.cpp, solar_sensor.cpp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]
2026-08-27 refactor(ota): extract IOtaController interface and cleanup IDayNightController
    - Create IOtaController interface matching pump-controller standard
    - Implement IOtaController in OtaController and inject interface into SolarSensor
    - Add MockOtaController and simplify test_solar_sensor fixture
    - Remove obsolete calculate_solar_day method from IDayNightController and DayNightController
    - Verify all host unit tests (74/74) and target firmware build pass
    [day_night_controller.cpp, solar_sensor.cpp]
2026-08-28 docs: kicad schematics files
    [solar-sensor.kicad_sch]
2026-08-29 fix(ina): prevent cache error panic by removing vtable access in ISR and disarming on dusk
    - Cache TaskHandle_t directly in SolarSensor to avoid vtable lookups from Flash inside IRAM ISR
    - Disarm INA alert GPIO ISR handler upon detecting dusk before NVS save and night transition
    - Bump version to 0.1.5
    [solar_sensor.cpp]
2026-08-29 fix(solar_sensor): prevent premature app_main exit and add destructor ISR cleanup
    - Return true on ota_requested when OTA does not restart to keep day cycle active
    - Add SolarSensor destructor to remove INA_ALERT_GPIO ISR handler on destruction
    - Use static storage duration for core application instances in app_main
    [main.cpp, solar_sensor.cpp]
2026-08-29 refactor(solar_sensor): deinit espnow during OTA download and use WiFiManager::connect
    - Deinitialize EspNowManager prior to OTA download to free heap and eliminate radio contention
    - Restore EspNowManager with proper channel policy and send status report on OTA fallback
    - Replace obsolete connect_wifi_with_retry with WiFiManager::connect
    [solar_sensor.cpp]
2026-08-29 refactor(solar_sensor): remove obsolete espnow_trigger dependency
    - Remove EspNowOtaTrigger injection and arm/disarm calls from SolarSensor
    - Align OTA command processing with standard CommandHandler flow
    - Update unit tests in test_solar_sensor
2026-08-31 refactor: replace hardcoded location constants with configurable variables and remove obsolete defaults
    [main.cpp, test_day_night_controller.cpp]
2026-09-16 fix: add channel recovery and sync wifi start to solar sensor (v0.1.6)
    [solar_sensor.cpp, test_solar_sensor.cpp]

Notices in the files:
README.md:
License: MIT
